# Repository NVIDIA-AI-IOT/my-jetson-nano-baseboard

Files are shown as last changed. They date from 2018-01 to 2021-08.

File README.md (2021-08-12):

# My Jetson Nano Baseboard

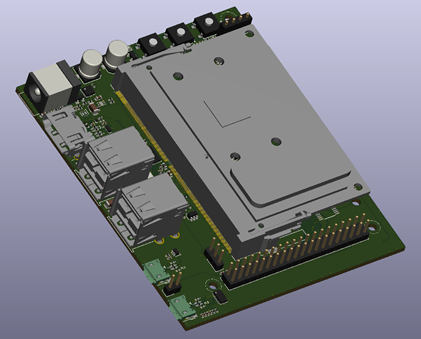
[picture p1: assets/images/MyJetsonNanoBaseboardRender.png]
Render of My Jetson Nano Baseboard

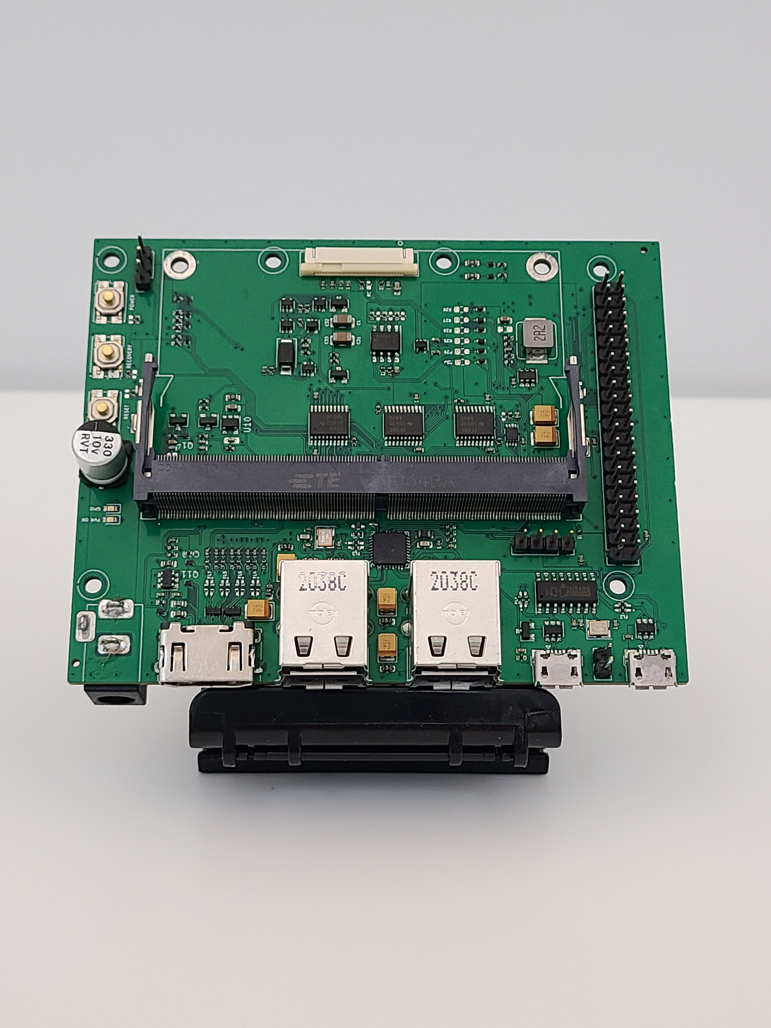
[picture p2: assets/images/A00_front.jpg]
Picture of My Jetson Nano Baseboard


This basic baseboard gives the user the foundation and the flexibility to design their own baseboard for the Jetson Nano. It also repurposes some of the Jetson Nano’s interface signals for simple beginner projects.

This baseboard, as designed, contains:
* A 5V, 4A DC barrel jack
* 4 USB 2.0 connectors
* An HDMI connector
* A UART-to-USB bridge
* A debug USB
* A 40-pin GPIO
* A servo header
* Three user-interactive buttons (power, reset, and force recovery)
* A flex connector for an OLED display

Use these files to kickstart your own application-specific baseboard or implement some quick and easy projects!

## Quick Start

You only need a computer to get started right now! For a more in-depth setup guide, check out `docs/setup.md`.
1.	Install the appropriate version of KiCAD, an open source schematic and layout design program, for your operating system [here](https://www.kicad.org/download/).
1.	Download this GitHub repository either as a ZIP or on the command line.
1.	Save the following symbol and footprint libraries to the “Design Files/Libraries” folder (you may have to make an account – alternatively, if you want the practice, you could try making them yourself):
	1.	[B3SL-1002P](https://octopart.com/b3sl-1002p-omron-9515385)
	1.	[TPD4E02B04DQAR](https://www.snapeda.com/parts/TPD4E02B04DQAR/Texas%20Instruments/view-part/)
	1.	[3-1734592-0](https://www.te.com/usa-en/product-3-1734592-0.html)
	1.	[DC-005-2.0A](https://www.snapeda.com/parts/DC-005/Best%20Inc./view-part/)
	1.	[ACM2012-201-2P-T001](https://www.snapeda.com/parts/ACM2012-201-2P-T001/TDK/view-part/1217094/)
	1.	[10029449-111RLF](https://octopart.com/10029449-111rlf-amphenol+icc+%2F+fci-90332945#CadModels)
	1.	[2309413-1](https://www.te.com/usa-en/product-2309413-1.html)

1.	Open the project (.pro) file in KiCAD.
1.	Add the symbol and footprint libraries as project-specific to your KiCAD program, following [this guide](https://support.snapeda.com/en/articles/2651507-how-to-import-into-kicad). You will know that the libraries are correctly loaded when there are no more boxes with question marks.
1.	You are now set up to tinker with the files and launch your own hardware designs!

Be sure to download the Jetson Nano Product Design Guide [here](https://developer.nvidia.com/embedded/downloads) (NVIDIA Developer account required) to help you with your design.

If you want to make your boards and test them, you’ll need the Jetson Nano module (not included, can be bought as part of the developer kit [here](https://developer.nvidia.com/embedded/jetson-nano-developer-kit)). It is also helpful to have electronics equipment like an oscilloscope, a multimeter, and a soldering iron.

## Questions and Improvements

If you have a suggestion, please open an [issue](https://github.com/NVIDIA-AI-IOT/my-jetson-nano-baseboard/issues/new) on GitHub.

Please share your projects with us on the [Jetson Developer Forums](https://forums.developer.nvidia.com/c/agx-autonomous-machines/jetson-embedded-systems/70).

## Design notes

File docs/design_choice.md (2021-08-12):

# Design Justifications

## Introduction

This document details choices made and tradeoffs considered in designing this board, with the aim of informing makers' design decisions and elucidating the design process.

To the extent possible, the board was designed for simplicity of manufacturing and affordability. Parts were selected from the manufacturer's (JLCPCB) parts library, and the number of resistors and capacitors was reduced by standardizing pullup and pulldown resistor (1k, 10k, or 100k) and decoupling capacitor (0.1uF) values. When a suggested layout was provided by a manufacturer on a datasheet, it was used. For ease of use, footprints of components that were not stuffed were indicated in silkscreen so they could be easily found, while stuffed components were not silkscreened to reduce clutter.

## Power

Power planes were used to improve power connections and raise current limits, and were placed on the exterior layers, which have thicker copper than the interior layers, to improve conductivity. Decoupling capacitors were added to power rails to filter out high-frequency noise.

No power protection is provided after the barrel jack, as it is assumed that the power supply is stable and at the correct voltage. Additional over/under current/voltage protection can be added by the user.

The topology of the Buck converter (U7) was determined using TI's WBENCH tool, and a 100 Ohm resistor was added in series with the resistor so that high-frequency noise could be injected during validation to measure stability.

## Signal Integrity

### Reducing Interference

Electrostatic discharge (ESD) and electromagnetic interference (EMI) can cause circuit malfunctions and damage on-board components. ESD diodes with at least 8kV protection were added to major interfaces, and were placed near the connectors to stop voltage spikes close to the source. Ground stitching vias were added in a uniform pattern around the board to prevent EMI. Each copper layer was filled with a GND plane where there were no other copper fills, which also helped balance the deposits on the board. For further EMI protection, optional common mode chokes footprints were also provided near connectors.

### Design for High Speed

High-speed interfaces were laid out first, and the design rules concerning inter-pair and intra-pair skew, via topology, and more in the Jetson Nano Product Design Guide were followed. Interface speeds are the following: 

| Interface/Signal | Speed | Type |
|---|---|---|
| HDMI | 5.94 Gbps | High-speed |
| UART | 5 Mbps max | Low-speed |
| I2C | 5 Mbps max | Low-speed |
| I2S | 3.125 Mbps max | Low-speed |
| SPI | 65 MHz max frequency | Medium-speed |
| USB2.0 | 480 Mbps | High-speed |
| GPIOs from module | ? | Low-speed |

HDMI was routed first, then USB2.0, then all else.

Differential pairs have strict spacing and trace width requirements, determined based on impedance requirements, that can be set in KiCAD using net classes. The length and skew of a differential pair can be adjusted using KiCAD's differential pair tools. Special care was taken for HDMI traces in particular since they are very high speed. The space under HDMI pads was voided to avoid introducing capacitive effects, and GND return vias were placed in the line of sight to any HDMI signal vias.

### Other considerations

A maximum of 45 degree angles were used during layout - anything sharper, and the signal may be damaged.

## Component Placement

The form factor was based on the Jetson Nano: a four-layer board was chosen, the same shape was used, connectors were placed in the same locations. This was helpful in avoiding potential interference between the sheaths of connectors plugged in at the same time. Interference of other connectors, including the fan header and GPIO header, was checked by drawing the outline of jumper wires. The form factor did create some challenges, notably with the OLED display - there wasn't enough space to support the display on the board, so the connector was placed to have the display cantilevered. To provide more support, two holes were drilled on either side of the connector, so that the user could design their own mounting scheme if they wanted to.

Components were placed together by functionality and by power requirements.

## Circuit Specifics

### Debug microUSB Connections

The transistor circuit detects whether the USB device is plugged in, which is necessary for interfacing with Tegra. Tegra's GPIO00 has a logic level of 1.8V, so the transistor circuit also acts as a level shifter to bring it to the USB level of 5V. This circuit is present on the existing Jetson Nano baseboard.

### EEPROM

The EEPROM is provided as an option for makers to write their own board firmware, which allows to differentiate between multiple versions of the same board. It is not required. The address of the EEPROM is 7'h57.

### UART to USB Bridge

CH340G was chosen due to its low cost, and the capacitor connections were determined based on the datasheet's application example. Because the module should be continually transmitting, CTS was grounded, RTS was left floating, and USB suspend/resume and remote wakeup were not used.

### Power ON/OFF Logic

Open-drain NAND gates are used due to timing requirements for power-on logic, as opposed to a D flipflop, and to reduce cost. Pullups R6 and R7 were added due to the gates being open-drain. The logic was simulated in LTSpice. 

The RC time constant of R2 and C32/C33 was chosen to be approximately 10s, even within resistor and capacitor tolerance, so that users can shut down the system within that time as expected. A large capacitance value was used since large resistors usually have undesirable parallel effects. 100 uF capacitors are large and expensive, so two 47uF capacitors were placed in parallel. Co-layout options (0805 and 1206) were provided so that the value of C32/C33 could be tuned during validation. R39 was added to limit current to the capacitors.

Finally, the buffers U1, U2, and U4 prevent loading effects from the S/R latch that might interfere with the logic.

### USB 2.0 Type A Hub

500 mA fuses and 100 uF capacitors were added to each connector, as per the USB specification. This prevents USB devices from drawing too much current and protects the module.

### Level Shifters

Level shifters are necessary because Tegra's GPIOs and UART signals have a 1.8V logic level, but 5V and 3.3V logic levels are expected, respectively. The GPIO header is compatible with PiHats and allows the user to power small devices from the header.

### OLED Display

All signals going to this display should be at 3.3V. The display was laid out using I2C, enabling users to practice using that protocol, although the display also supports 4-wire SPI as well as 8-bit 68XX and 80XX parallel microcontroller interfaces. The display's active-low reset is tied to the 3V3_PGOOD signal. The I2C address pin is pulled high, with the option of being pulled low.

Note that the connector's pin numbers are the opposite of the display's (i.e. pin 1 on the display is pin 24 on the board).

### HDMI Connections

A load switch was used with a current limit of 600 mA, the lowest possible for the load switch chip used. A load switch was used instead of a resettable fuse, which would be cheaper, because the HDMI specification requires the 5V power to be off when the module is in sleep mode.

## SODIMM Connector

Please do not force the module into the connector - doing so will irreparably damage it and cause signals to be misaligned.

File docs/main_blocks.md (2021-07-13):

# Functional Circuit Description

## Power

Power is provided via a barrel jack connector. The power supply should be 5V, 4A. 

> Please note that unlike the Jetson Nano, this baseboard's design does not allow for powering through the micro USB connector or the GPIO header.

A Buck converter is used to step down the voltage from 5V to 3.3V, and a low dropout regulator is used to translate the 3.3V rail to 1.8V.

| 5V | 3.3V | 1.8V |
|---|---|---|
| Jetson Nano Module | OLED Display  | Level Shifter |
| Debug microUSB | USB Hub Chip  | EEPROM |
| Servo Header | Level Shifter | |
| HDMI | HDMI | |
| GPIO Header | GPIO Header | |

Power required for each interface.

## Display

HDMI is provided as a display for the monitor. The HDMI lines use the DP1 class of signals on the module. The Jetson Nano module also supports DisplayPort signals, which can be added to the board.

## GPIO Header

This board replicates the Jetson Nano's 40-pin GPIO header. The pinout is compatible with the PiHat boards and is available on [pinout.xyz](https://pinout.xyz/). The GPIO header contains I2C, SPI, GPIOs, UART signals and 5V, 3.3V, and GND power rails.

## USB Connections

### Debug USB Header

The debug USB header is a microUSB type B connector. It enables the board to enter force recovery mode, in which the operating system is not loaded and the board becomes a USB device that can be written to from a host computer. It corresponds to USB0 on the module.

### UART to USB Bridge

The UART to USB Bridge is a microUSB type B connector that allows the user to connect a device to the Jetson Nano via UART. It corresponds to the UART2 lines on the module.

### USB 2.0 Type A

There are four USB 2.0 Type A connections. These can be used for keyboards, mouses, cameras, and more. These are managed through a USB hub chip and correspond to the USB1 lines on the module.

## EEPROM

The EEPROM is used interally to identify the board and is provided as an option for developers who wish use it in writing their own firmware. It can be written to on the I2C2 lines, and its address is 7'h57.

## OLED Display

A flex connector for an OLED display is provided using the I2C0 lanes. The schematic can be edited to use three or four wire SPI or 8-bit 68XX or 80XX parallel to interface with the OLED Display.

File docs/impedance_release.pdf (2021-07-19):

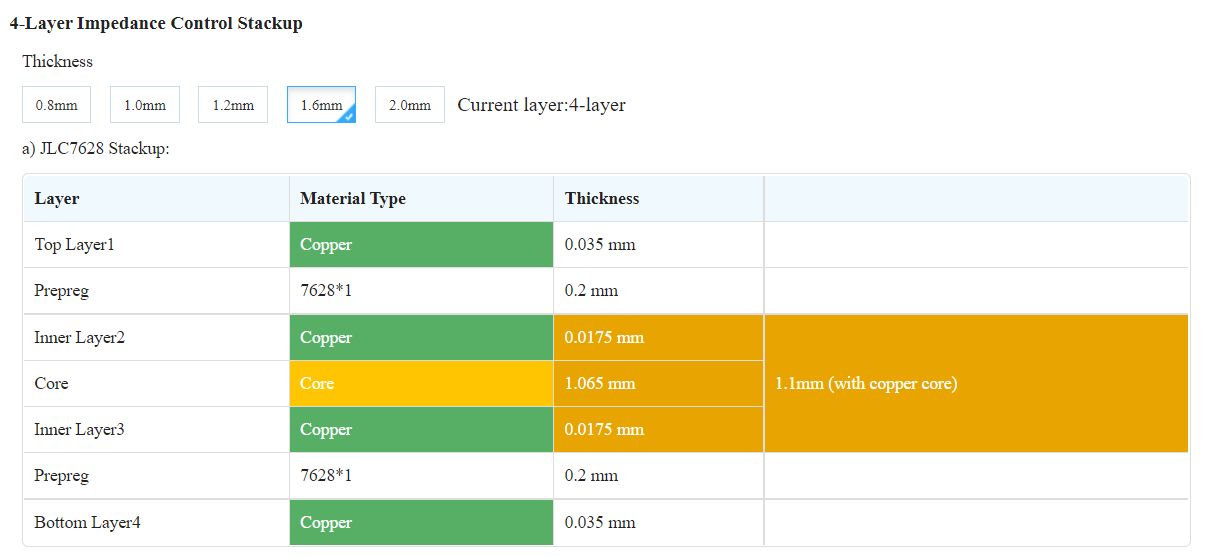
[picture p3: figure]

Using standard JLCPCB 1.6mm stackup, https://cart.jlcpcb.com/impedance

All tolerances +/- 10%

Single Ended | DEZ | SEZ | LW | LineGap | Ref (above) | Ref (below)
TOP | | 50 | 0.1016 | | | L2
BOTTOM | | 50 | 0.1016 | | L3

Target impedance for USB pairs is 90 Ohm. Target impedance for HDMI pairs is 100 Ohm.

Differential (edge) | DEZ | SEZ | LW | LineGap | Ref (above) | Ref (below)
TOP | 85 | | 0.2 | 0.102 | | L2
TOP | 90 | | 0.18 | 0.102 | | L2
TOP | 95 | | 0.1524 | 0.102 | | L2
TOP | 100 | | 0.1524 | 0.1524 | | L2
TOP | 105 | | 0.1524 | 0.179 | | L2
BOTTOM | 85 | | 0.2 | 0.102 | L3
BOTTOM | 90 | | 0.18 | 0.102 | L3
BOTTOM | 95 | | 0.1524 | 0.102 | L3
BOTTOM | 100 | | 0.1524 | 0.1524 | L3
BOTTOM | 105 | | 0.1524 | 0.179 | L3

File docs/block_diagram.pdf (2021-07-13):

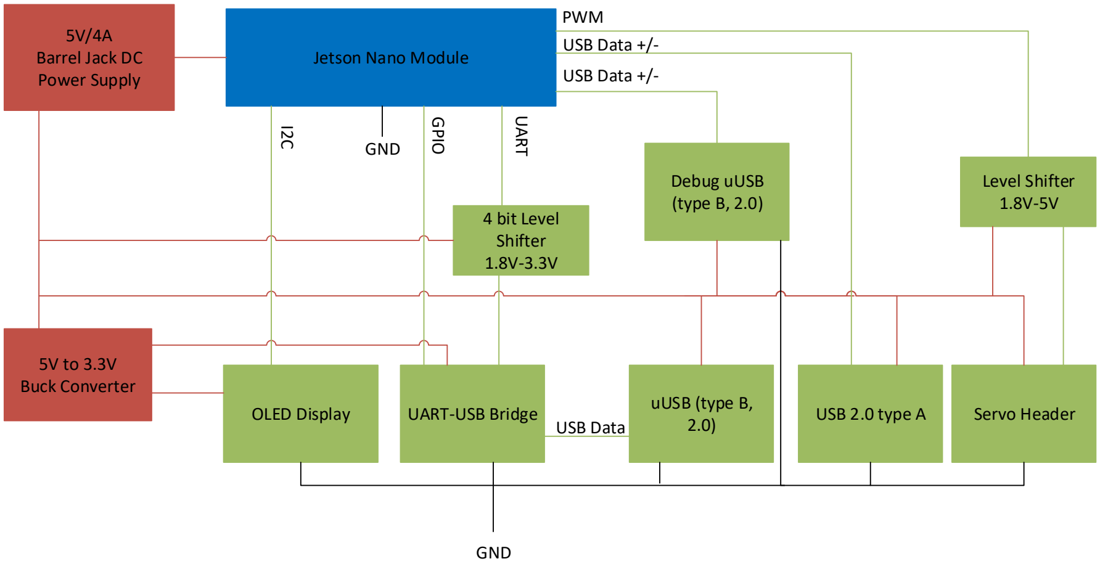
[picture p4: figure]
OLED Display; 5V/4A Barrel Jack DC Power Supply; 5V to 3.3V Buck Converter; Jetson Nano Module; UART-USB Bridge; Servo Header uUSB (type B,; 2.0) USB 2.0 type A; PWM; GND; 4 bit Level Shifter 1.8V-3.3V; GPIO; USB Data +/-; USB Data; Debug uUSB (type B, 2.0); UART; Level Shifter 1.8V-5V

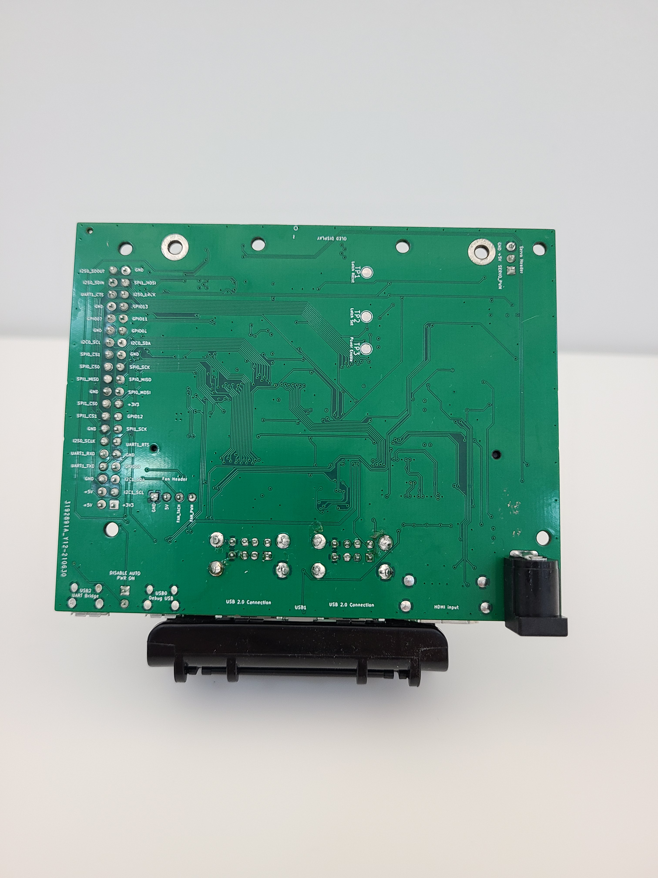
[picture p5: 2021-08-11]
assets/images/A00_back.jpg

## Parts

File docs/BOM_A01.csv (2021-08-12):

Datasheet | Part Number | Designator | Footprint | LCSC Part
https://datasheet.lcsc.com/lcsc/1810191219_Samsung-Electro-Mechanics-CL05B104KO5NNNC_C1525.pdf | CL05B104KO5NNNC | C10, C11, C12, C13, C14, C15, C16, C28, C29, C30, C36, C37, C38, C39, C40, C44, C47, C48, C49, C50, C51, C52, C53, C54, C55, C56, C59, C60, C62, C63, C70, C71 | 0402 | C1525
https://datasheet.lcsc.com/szlcsc/Samsung-Electro-Mechanics-CL05A475MP5NRNC_C23733.pdf | CL05A475MP5NRNC | C2, C8, C17 | 0402 | C23733
https://datasheet.lcsc.com/lcsc/1810191219_Samsung-Electro-Mechanics-CL10A106KP8NNNC_C19702.pdf | CL10A106KP8NNNC | C20, C72 | 0603 | C19702
https://datasheet.lcsc.com/szlcsc/AVX-TAJB107K006RNJ_C16133.pdf | TAJB107K006RNJ | C22, C23, C66, C67, C68, C69 | CASE-B_3528 | C16133
https://datasheet.lcsc.com/lcsc/2105211807_Honor-Elec-RVT1A331M0810_C113284.pdf | RVT1A331M0810 | C24 | CAP-SMD | C113284
https://datasheet.lcsc.com/lcsc/1811141710_FH-Guangdong-Fenghua-Advanced-Tech-0402CG6R8C500NT_C1576.pdf | 0402CG6R8C500NT | C25 | 0402 | C1576
https://datasheet.lcsc.com/szlcsc/Samsung-Electro-Mechanics-CL05A105KA5NQNC_C52923.pdf | CL05A105KA5NQNC | C3, C4, C18, C19 | 0402 | C52923
https://datasheet.lcsc.com/lcsc/1810221121_Samsung-Electro-Mechanics-CL31A476MPHNNNE_C96123.pdf | CL31A476MPHNNNE | C32, C33 | 1206 | C96123
https://datasheet.lcsc.com/lcsc/1809291524_FH-Guangdong-Fenghua-Advanced-Tech-0402B102K500NT_C1523.pdf | 0402B102K500NT | C41 | 0402 | C1523
https://datasheet.lcsc.com/szlcsc/Guangdong-Fenghua-Advanced-Tech-0603B103K500NT_C57112.pdf | 0603B103K500NT | C45, C61 | 0603 | C57112
https://datasheet.lcsc.com/szlcsc/Guangdong-Fenghua-Advanced-Tech-0402CG150J500NT_C1548.pdf | 0402CG150J500NT | C57, C58, C64, C65 | 0402 | C1548
https://datasheet.lcsc.com/lcsc/1811141731_FH-Guangdong-Fenghua-Advanced-Tech-0402CG330J500NT_C1562.pdf | 0402CG330J500NT | C73, C74 | 0402 | C1562
https://datasheet.lcsc.com/lcsc/2007141104_MDD-Microdiode-Electronics-SS14_C2480.pdf | SS14 | D1 | SMA,DO-214AC | C2480
https://datasheet.lcsc.com/lcsc/2005212035_TECH-PUBLIC-TPD1E10B06DPYR-TP_C558445.pdf | TPD1E10B06DPYR-TP | D12, D13, D14, D15, D16, D17 | DFN1006-2 | C558445
https://datasheet.lcsc.com/lcsc/1809131529_Texas-Instruments-TPD4E02B04DQAR_C106794.pdf | TPD4E02B04DQAR | D18, D19 | uSON-10 | C106794
https://datasheet.lcsc.com/szlcsc/2005211235_TECH-PUBLIC-TPUSBLC6-2SC6_C558442.pdf | USBLC6-2SC6 | D2, D5, D9, D10, D11, D20 | SOT-23-6 | C558442
https://datasheet.lcsc.com/lcsc/1809051321_LRC-LBAS70-05LT1G_C131857.pdf | LBAS70-05LT1G | D4 | SOT-23-3 | C131857
https://datasheet.lcsc.com/szlcsc/Everlight-Elec-19-217-GHC-YR1S2-3T_C72043.pdf | 19-217/GHC-YR1S2/3T | D6 | LED_0603 | C72043
https://datasheet.lcsc.com/lcsc/1811101510_Everlight-Elec-19-217-BHC-ZL1M2RY-3T_C72041.pdf | 19-217/BHC-ZL1M2RY/3T | D7 | LED_0603 | C72041
https://datasheet.lcsc.com/lcsc/1811141711_Sunlord-GZ2012D601TF_C1017.pdf | GZ2012D601TF | FB1 | 0805 | C1017
https://datasheet.lcsc.com/lcsc/1811151421_Ckmtw-Shenzhen-Cankemeng-B-2100S02P-A110_C124375.pdf | B-2100S02P-A110 | J1 | HDR-TH_2P-P2.54-V | C124375
https://file.elecfans.com/web1/M00/BA/94/o4YBAF6eu2GABUqoAAdPfgsQimA612.pdf?filename=210S-1_2P.pdf | C124376 | J10 | HDR-TH_3P-P2.54-V | C124376
http://portal.fciconnect.com/Comergent//fci/drawing/10029449.pdf | 10029449-111RLF | J11 | HDMI SMT | C427307
https://www.te.com/usa-en/product-2-1734839-4.html | 2-1734839-4 | J2 | 24 pin SMT | -
https://file.elecfans.com/web1/M00/A7/25/pIYBAF2B1q6AKkTfABbJAnUjDHU127.pdf?filename=DC-005-5A-2.0.pdf | DC-005-5A-2.0 | J3 | THT | C381116
https://file.elecfans.com/web1/M00/BA/94/o4YBAF6eu2GABUqoAAdPfgsQimA612.pdf?filename=210S-1_2P.pdf | 210-91-04GB01 | J4 | THT | C390680
https://www.te.com/usa-en/product-2309413-1.html | 2309413-1 | J5 | SMT | -
https://file.elecfans.com/web1/M00/BA/94/o4YBAF6eu2GABUqoAAdPfgsQimA612.pdf?filename=210S-1_2P.pdf | 12251220ANG0S115001 | J6 | HDR-TH_40P-P2.54-V-M-R2-C20-S2.54 | C429965
https://datasheet.lcsc.com/lcsc/1912111437_Amphenol-ICC-10103594-0001LF_C428495.pdf | 10103594-0001LF | J7 | MICRO-USB-SMD | C428495
https://datasheet.lcsc.com/lcsc/1912111437_Amphenol-ICC-10103594-0001LF_C428495.pdf | 10103594-0001LF | J8 | MICRO-USB-SMD | C428495
https://www.molex.com/webdocs/datasheets/pdf/en-us/0672983090_IO_CONNECTORS.pdf | 672983090 | J9, J12 | USB-THT | C588408
https://datasheet.lcsc.com/lcsc/1912111437_Sunlord-MWSA0503S-2R2MT_C408408.pdf | MWSA0503S-2R2MT | L1 | SMD-5.2x5.4x2.8 | C408408
https://datasheet.lcsc.com/lcsc/1811081616_Murata-Electronics-LQP15MN1N2B02D_C77117.pdf | LQP15MN1N2B02D | L2 | 0402 | C77117
https://datasheet.lcsc.com/lcsc/1810262112_UG-Univision-Semicon-UG-2864KSWMG01_C88331.pdf | UG-2864KLBMG01 | OLED Display | - | C88331
https://www.fairchildsemi.com/datasheets/2N/2N7002.pdf | 2N7002 | Q1, Q2, Q5 | SOT-23 | C8545
https://www.diodes.com/assets/Datasheets/ds31854.pdf | DMN26D0UT-7 | Q3, Q4, Q6, Q7, Q9, Q10, Q11, Q12, Q13, Q14 | SOT-523 | C211407
https://www.diodes.com/assets/Datasheets/ds31835.pdf | MMBT3904 | Q8 | SOT-23 | C20526
https://datasheet.lcsc.com/szlcsc/Uniroyal-Elec-0402WGF1002TCE_C25744.pdf | 0402WGF1002TCE | R1, R5, R6, R7, R13, R14, R15, R17, R20, R24, R33, R34, R35, R40, R50, R52, R54, R56, R58, R71, R72, R79, R89, R90 | 0402 | C25744
https://datasheet.lcsc.com/lcsc/1811022110_UNI-ROYAL-Uniroyal-Elec-0402WGF2201TCE_C25879.pdf | 0402WGF2201TCE | R10 | 0402 | C25879
https://datasheet.lcsc.com/lcsc/1811011222_UNI-ROYAL-Uniroyal-Elec-0402WGF3901TCE_C51721.pdf | 0402WGF3901TCE | R11 | 0402 | C51721
https://datasheet.lcsc.com/lcsc/1810111814_UNI-ROYAL-Uniroyal-Elec-0402WGF1003TCE_C25741.pdf | 0402WGF1003TCE | R12, R18, R19, R38, R82, R83, R84, R85, R86, R87, R88 | 0402 | C25741
https://datasheet.lcsc.com/lcsc/1810301112_UNI-ROYAL-Uniroyal-Elec-0402WGF5101TCE_C25905.pdf | 0402WGF5101TCE | R16 | 0402 | C25905
https://datasheet.lcsc.com/lcsc/1810301322_UNI-ROYAL-Uniroyal-Elec-0402WGF3003TCE_C25774.pdf | 0402WGF3003TCE | R2 | 0402 | C25774
https://datasheet.lcsc.com/lcsc/1809140113_UNI-ROYAL-Uniroyal-Elec-0402WGF1000TCE_C25076.pdf | 0402WGF1000TCE | R21, R39 | 0402 | C25076
https://datasheet.lcsc.com/szlcsc/Uniroyal-Elec-0402WGF1001TCE_C11702.pdf | 0402WGF1001TCE | R23 | 0402 | C11702
https://datasheet.lcsc.com/szlcsc/Uniroyal-Elec-0402WGF1202TCE_C25752.pdf | 0603WAF1202T5E | R3 | 603 | C22790
https://datasheet.lcsc.com/lcsc/1811081724_UNI-ROYAL-Uniroyal-Elec-0603WAF1500T5E_C22808.pdf | 0603WAF1500T5E | R32, R37 | 0603 | C22808
https://datasheet.lcsc.com/szlcsc/Uniroyal-Elec-0402WGF4701TCE_C25900.pdf | 0402WGF4701TCE | R4, R22 | 0402 | C25900
https://datasheet.lcsc.com/lcsc/1809301716_UNI-ROYAL-Uniroyal-Elec-0402WGF1004TCE_C26083.pdf | 0402WGF1004TCE | R43 | 0402 | C26083
https://datasheet.lcsc.com/lcsc/1811151223_UNI-ROYAL-Uniroyal-Elec-0402WGF5100TCE_C25123.pdf | 0402WGF5100TCE | R59, R60, R61, R62, R63, R64, R65, R66 | 0402 | C25123
https://datasheet.lcsc.com/lcsc/1811081714_UNI-ROYAL-Uniroyal-Elec-0603WAF1801T5E_C4177.pdf | 0603WAF1801T5E | R77, R78 | 603 | C4177
https://datasheet.lcsc.com/szlcsc/Uniroyal-Elec-0402WGF0000TCE_C17168.pdf | 0402WGF0000TCE | R8, R31, R36, R41, R42, R44, R46, R47, R48, R49, R57, R67, R68, R69, R70, R73, R74, R75, R76 | 0402 | C17168
https://datasheet.lcsc.com/lcsc/1811081724_UNI-ROYAL-Uniroyal-Elec-0603WAF3602T5E_C23147.pdf | 0603WAF3602T5E | R80 | 0603 | C23147
https://datasheet.lcsc.com/szlcsc/Uniroyal-Elec-0402WGF1203TCE_C25750.pdf | 0402WGF1203TCE | R81 | 0402 | C25750
https://datasheet.lcsc.com/lcsc/1811081713_UNI-ROYAL-Uniroyal-Elec-0603WAF1102T5E_C25950.pdf | 0603WAF1102T5E | R91 | 0603 | C25950
https://datasheet.lcsc.com/lcsc/2002271432_XKB-Connectivity-TS-1187A-C-E-B_C318887.pdf | TS-1187A-C-E-B | S1, S2, S3 | SMD-SW-4_5.1x5.1x2.5 | C318887
https://datasheet.lcsc.com/lcsc/1810051613_TECHFUSE-SMD0603-050_C69679.pdf | SMD0603-050 | TH1, TH2, TH3, TH4 | 0603 | C69679
https://datasheet.lcsc.com/lcsc/1804240020_Nexperia-74LVC1G126GV-125_C12520.pdf | 74LVC1G126GW,125 | U1, U4 | SOT-353 | C55052
https://datasheet.lcsc.com/lcsc/1809291208_XI-AN-Aerosemi-Tech-MT9700_C89855.pdf | MT9700 | U10 | SOT-23-5 | C89855
https://datasheet.lcsc.com/lcsc/1809291612_Texas-Instruments-TXB0102DCUR_C60709.pdf | TXB0102DCUR | U15 | VSSOP-8_2.0x2.3x0.5P | C60709
https://datasheet.lcsc.com/lcsc/2008191806_WCH-Jiangsu-Qin-Heng-CH340G_C14267.pdf | CH340G | U16 | SOIC-16_3.9x9.9x1.27P | C14267
https://datasheet.lcsc.com/lcsc/1912112237_Microchip-Tech-AT24CS01-SSHM-T_C461563.pdf | AT24CS01-SSHM | U18 | SOIC-8 | C461563
https://datasheet.lcsc.com/lcsc/2008250208_ON-Semiconductor-MC74VHC1G07DFT2G_C603274.pdf | MC74VHC1G07DFT2G | U2 | TSSOP-5 | C603274
https://datasheet.lcsc.com/szlcsc/1810010411_Diodes-Incorporated-AP2281-3WG-7_C128634.pdf | AP2281-3WG-7 | U22 | SOT-26-6 | C128634
https://datasheet.lcsc.com/lcsc/1809200830_Microchip-Tech-USB2514B-AEZC-TR_C16251.pdf | USB2514B-AEZC-TR | U23 | QFN-36_6x6x05P | C16251
https://datasheet.lcsc.com/lcsc/1809111614_ON-Semiconductor-MC74VHC1G01DFT1G_C150244.pdf | MC74VHC1G01DFT1G | U3, U24 | SOT-353 | C150244
https://datasheet.lcsc.com/lcsc/1809192314_Texas-Instruments-TXS0108EPWR_C17206.pdf | TXS0108EPWR | U5, U6, U9 | TSSOP-20_4.4x6.5x0.65P | C17206
https://datasheet.lcsc.com/lcsc/2010150204_Texas-Instruments-TLV62569PDDCR_C398365.pdf | TLV62569PDDC | U7 | SOT-23-Thin-6 | C398365
https://datasheet.lcsc.com/lcsc/1912112237_Richtek-Tech-RT9193-18GU5_C425792.pdf | RT9193-18GU5 | U8 | SC70-5 | C425792
https://datasheet.lcsc.com/lcsc/2103291204_Yangxing-Tech-X322524MMB4SI_C70583.pdf | X322524MMB4SI | Y1 | SMD-3225_4P | C70583
https://datasheet.lcsc.com/szlcsc/Yangxing-Tech-X322512MSB4SI_C9002.pdf | X322512MSB4SI | Y2 | SMD-3225_4P | C9002

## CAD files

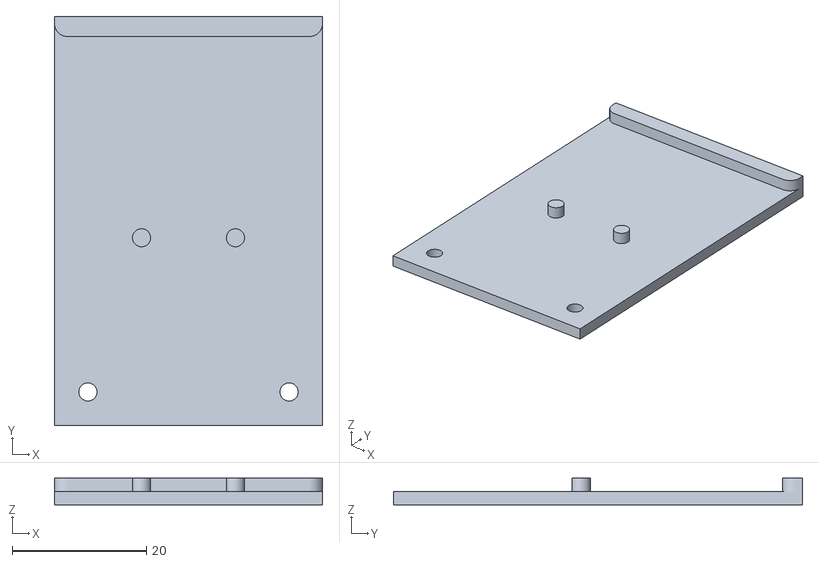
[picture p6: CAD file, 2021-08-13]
sampleproj/OLED Display Support.stl
40.0 x 61.0 x 4.00

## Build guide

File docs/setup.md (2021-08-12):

# Getting Started with My Jetson Nano Baseboard

## 0. Introduction

My Jetson Nano Baseboard enables makers to design their own baseboards for the Jetson Nano module. The provided design differs from the Jetson Nano's baseboard in that it contains fewer high-speed interfaces, although these can be added by the maker. The My Jetson Nano Baseboard also includes sample projects that allow the user to experiment with I2C and GPIOs.

This baseboard, as designed, contains:

- A 5V, 4A DC barrel jack
- 4 USB 2.0 connectors
- An HDMI connector
- A UART-to-USB bridge
- A debug USB
- A 40-pin GPIO
- A servo header
- Three user-interactive buttons (power, reset, and force recovery)
- A flex connector for an OLED display

These interfaces can be customized according to the maker's needs. The files are provided as-is and may contain errors (if you find one, open an issue).

Use these files to kickstart your own application-specific baseboard or implement some quick and easy projects! It is our hope that this project will contribute to the Open Hardware movement.

## 1. Setting Up Software

These files were created with KiCAD, a free and open-source electronics design suite including schematic capture and PCB layout. Although there are other FOSS electronics programs, KiCAD is widespread and has the most extensive professional features.

You can download KiCAD from their official website [here](https://www.kicad.org/download/).

KiCAD itself needs very little setup, but these files require you to set up some libraries. First, download the files in this repository as a ZIP or on the command line. 

> If you download my-jetson-nano-baseboard as a ZIP, be sure to unzip the folder. If you do not do this, KiCAD will not be able to access sub-pages in the repository and your schematic will be empty.

Some symbol and footprint libraries are included with the download of the files in this repository, located in the design/libraries folder. Others will need to be downloaded:

1.	[B3SL-1002P](https://octopart.com/b3sl-1002p-omron-9515385)
1.	[TPD4E02B04DQAR](https://www.snapeda.com/parts/TPD4E02B04DQAR/Texas%20Instruments/view-part/)
1.	[DC-005-2.0A](https://www.snapeda.com/parts/DC-005/Best%20Inc./view-part/)
1.	[ACM2012-201-2P-T001](https://www.snapeda.com/parts/ACM2012-201-2P-T001/TDK/view-part/1217094/)
1.	[10029449-111RLF](https://octopart.com/10029449-111rlf-amphenol+icc+%2F+fci-90332945#CadModels)
1.	[67298-3090-0](https://octopart.com/67298-3090-molex-7124952#Specs)
1.	[2309413-1](https://www.te.com/usa-en/product-2309413-1.html)

To set these up, open the project (.pro) file and navigate to Preferences > Manage Symbol Libraries > Project Specific Libraries, and add the relevant library with the plus sign. Repeat for footprint libraries. 

Upon reopening the schematic file, boxes with question marks should be replaced by symbols. If the boxes with question marks remain, you may have to re-select the proper symbol for the pat from the library.

To run the sample projects, you will need several Python libraries. They can be installed using pip with the following command:

> pip3 install Jetson.GPIO smbus2 machine

Because this operation requires internet, I recommend switching the module to the official baseboard and connecting it to the internet via Ethernet.

## 2. Editing & Designing

Printed Circuit Boards can be manufactured directly from the provided Gerber files, though you may wish to edit the files to better suit your use. If you are unfamiliar with KiCAD, SparkFun has a [nice beginner's guide](https://learn.sparkfun.com/tutorials/beginners-guide-to-kicad) that covers the workflow and basic actions.

Here are some changes you may want to make:

1.	Adding or removing an interface
	- The Jetson Nano Product Design Guide, available on NVIDIA's [Jetson Downloads Center](https://developer.nvidia.com/embedded/downloads), details the signals on the Jetson Nano module and the interfaces it supports.
1.	Changing the form factor of the board
	- This can be done easily in KiCAD by changing the "Edge Cuts" layer to reflect your preferred shape, moving the components outside of that zone, and re-routing.
1.	Replacing parts of the design
	- If the parts specified are no longer available, too expensive, or you want to change them for another reason, replace them on the schematic. Be sure to pick a new footprint for your chosen part.

If you choose to change the files, be sure to run a Design Rules Check (in KiCAD, represented by a ladybug) and review your design yourself in order to limit mistakes.

### Example: Removing the HDMI Connector

When removing the HDMI connector, you'll have to remove the connector itself and the peripherals that are required for the proper operation of HDMI. These will be on the "HDMI Connections" pages. Remove every part on those pages, then look at the rest of the document to identify any HDMI connections you've broken. In this case, there are a number of HDMI signals going to the module - you will want to mark those as "not connected".

Having removed the HDMI connections on the schematic, you then need to remove them on the layout. Generate a new netlist from the schematic, then load that into the PCB editor. You'll see far fewer components than before - you can use the extra space to make the board smaller, if you wish.

## 3. Making your boards

PCBs can be manufactured pretty inexpensively nowadays, so it's possible to make your boards. When choosing a manufacturer, consider the lead time, cost, and functionality. Many will give you a price estimate directly on their websites when uploading your files. Note that some parts, like the 260-pin SODIMM connector will be difficult to solder by hand, so it's helpful to have the manufacturer do that for you (not all support assembly). If you do have to solder complicated components by hand, it's helpful to order stencils, which will allow you to deposit solder paste very precisely. Some places will add them in for free or cheaply when you place your order.

Manufacturers will ask for Gerber files (provided as `manufacturing/gerbers_release.zip`), which contain instructions on where to lay copper on each layer. Drill files, also in that .zip, are also necessary to drill vias. If you are asking for assembly, the `manufacturing/assemble-top-pos.csv` is required.

## 4. Verifying the boards

There are four main stages to validation:
* Bringup
	* Before powering on the board, check for shorts between power rails, and ensure the characteristics of diodes and transistors are accurate to the datasheet. This is the most important part of validation, and for the most part can be done with just a multimeter.
* Functionality
	* Powering on the board and testing all interfaces to make sure they work. This can be done with scripts in some cases - those are in `../validation`.
* Power
	* Testing the efficiency, noise, and other characteristics of power sources, as well as ensuring power sequence signals are correct. Needs an oscilloscope.
* IO Electrical
	* Ensuring that interfaces meet electrical specifications, where appropriate. This must be done with an oscilloscope.

Enjoy your new baseboard!

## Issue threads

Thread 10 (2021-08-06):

Make silkscreen more readable

wolframalexa, 2021-08-06:
* Increase silkscreen size from 0.5x0.5mm to 0.438x0.7mm to make the text more readable.
* Add polarity for all ICs and polarized components to aid in soldering
* Add silkscreen on front for 40-pin header

Closed 2021-08-13.

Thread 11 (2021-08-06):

Incorrect footprints

wolframalexa, 2021-08-06:
* Flip DC Jack (J1) footprint to solder it on top
* GPIO header flipped - pin 1 should be towards outside edge of board

Closed 2021-08-13.

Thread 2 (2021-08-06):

Power LED does not light up on some boards

wolframalexa, 2021-08-06:
**Problem**
On some boards, the power LED D6 does not light, even though the board completes its power-on sequence and has booted normally.

**Release**
A00, no modifications

**Observed Behavior**
* The LED is the correct direction
* The board completes its power on sequence and the software functions as expected
* GPIO04 remains LOW at 0.6V, even though it should be driven HIGH upon power-up
* There is no measured voltage drop across R32
* There is an insufficient voltage drop across D6

**Root Cause Theory**
The gate threshold voltage varies depending on the individual transistor. It could be that this transistor has a higher V_GS and does not turn on when GPIO04 is at 0.6V. Additionally, the transistor Q7 could be misaligned.

**Suggested Next Steps**
* Investigate behavior of GPIO04, which should be HIGH upon power-on. Remove R31 to ensure no loading effects from transistor.
* Change all transistors DMN26D0UFB4-7 to the DMN26D0UT-7, which is in a larger SOT-523 package, to avoid misalignments.

wolframalexa, 2021-08-09:
Added 10k pullup R89 to 1v8 between R31 and gate of Q7.

Closed 2021-08-13.

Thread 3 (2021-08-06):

Low-resolution HDMI (1280x720)

wolframalexa, 2021-08-06:
**Problem**
The maximum HDMI resolution seems to be 1280x720, whereas the Jetson Nano achieves a resolution of 2560x1440. As a result, the display appears zoomed in.

**Release**
A00, no modifications

**Observed Behavior**
* This is present on all boards, with the same module as on the official baseboard - probably a hardware design issue, and not a software issue
* The resolution on the official Jetson Nano is twice that of "My Jetson Nano Baseboard"

**Root Cause Theory**
Resistor values may need to be tuned for better resolutions. Additionally, an EEPROM may be read to confirm HDMI resolution.

**Suggested Next Steps**
Investigate L4T behavior with regard to HDMI and resistor tuning on CEC line.

Closed 2021-08-13.

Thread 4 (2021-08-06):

Some USB 2.0 type A ports are not functional

wolframalexa, 2021-08-06:
**Problem**
Some USB ports on some boards do not respond when a USB mouse or keyboard is plugged into them.

**Observed Behavior**
When a USB mouse or keyboard is plugged into one of the four type A ports, it occasionally does not work (the pointer does not move, no text appears on screen). This hinders the ability for the user to interact with the display, and to use the USB devices they need.

**Root Cause Theory**
This is only present on some ports on some boards; it could be a manufacturing or hub chip error.

**Suggested Next Steps**
* Visually check all USB components to ensure there is no damage
* Ensure hub chip is strapped correctly
* Ensure USB layout guidelines are followed for signal integrity

wolframalexa, 2021-08-09:
Soldermask clearance around the USB pads is not sufficient; as a result, during rework, technicians had to scrape the mask off. This could cause poor electrical connections. I added additional soldermask clearance around the USB pads in A01.

Closed 2021-08-13.

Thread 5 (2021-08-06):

Fan PWM signal not in compliance

wolframalexa, 2021-08-06:
**Problem**
Users cannot use a fan, because the fan PWM signal is not in electrical compliance.

**Observed Behavior**
GPIO14 provides a nice PWM signal, but the signal becomes less crisp as it goes through the level shifter. In both images below,   the blue line is the FAN_PWM_LS node. Yellow: left = GPIO14, right = FAN_PWM_INV.

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

The transistor Q3 should invert the PWM signal, but does not appear to do so.

**Root Cause Theory**
At 20kHz, it is unlikely the fan signal is switching too fast for the transistor. It may be due to a transistor misalignment; switch from the DMN26D0UFB4-7 to the DMN26D0UT-7, which is in a larger SOT-523 package, to avoid misalignments.

**Suggested Next Steps**
Ask a more experienced engineer. May need a larger pullup, or more power control.

wolframalexa, 2021-08-09:
Removed Q3 and measured the fan PWM remaining high - showing that this is likely due to a transistor misalignment. Will switch to larger package for A01.

Closed 2021-08-13.

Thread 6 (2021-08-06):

OLED display does not fit in specified connector

wolframalexa, 2021-08-06:
**Problem**
The specified OLED display does not fit in the specified connector. Users cannot use the display.

**Release**
A00, no modifications

**Observed Behavior**
The connector is too small for the display.

**Root Cause Theory**
Mistakes were made.

**Suggested Next Steps**
Choose new connector for display.

wolframalexa, 2021-08-11:
0.7mm pitch FFC/FPC connectors are rare, so I'm changing both the display and the connector for greater accessibility. This will be fixed in A01.

Closed 2021-08-13.

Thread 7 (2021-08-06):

Fails sleep/wake software cycle

wolframalexa, 2021-08-06:
**Problem**
Board cannot be wake from software; the physical button must be pushed.

**Release**
A00, no modifications

**Observed Behavior**
When running the `validation/sleep_func.sh` script, the device does not wake until the power button is pushed.

**Root Cause Theory**
An issue with how L4T interacts with the baseboard.

**Suggested Next Steps**
* Probe power logic signals to ensure sequencing is correct
* Read L4T documentation for power design

wolframalexa, 2021-08-09:
Edited validation script with new sleep/wake command - hardware is validated. Worth noting that rtc0 is the default clock to wake with - not rtc1. Further information can be found on NVIDIA's forums here: https://forums.developer.nvidia.com/t/rtc-wakeup-not-happening-in-jetson-tx2-4gb/173047

Closed 2021-08-09.

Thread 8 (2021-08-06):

Servo PWM signal does not switch logic levels, remains high

wolframalexa, 2021-08-06:
**Problem**
When running the `sampleproj/servo_pwm.py` script, SERVO_PWM remains high, even as the GPIO07 pin outputs a PWM signal.

**Release**
A00, no modifications

**Observed Behavior**
Servo PWM remains high even when PWM script is run.

GPIO07 at 40-pin header:
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

SERVO_PWM at servo header:
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

**Root Cause Theory**
The pullup could be too strong; the transistor connection may not be consistent across boards. This is another issue that switching to a larger package transistor should fix.

**Suggested Next Steps**
* Switch to larger package transistor (as in issue #5 & 2)
* Test additional boards to ensure transistor connection remains consistent

wolframalexa, 2021-08-09:
Additional boards also have this issue. Likely due to transistor misalignment - will change for A01.

Closed 2021-08-13.

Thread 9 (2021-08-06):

Incorrect SODIMM connector

wolframalexa, 2021-08-06:
Use TE's 2309413-1 instead of ADDR0111-P005A for J5. The key is the opposite and the 2309413-1's key placement is correct.

Closed 2021-08-13.

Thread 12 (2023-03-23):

Internet Component

jccatilo, 2023-03-23:
Hi!! Thank you very much for this, I've got the imports working and now designing my own pcb. I'm working on a custom basedboard for jetson nano. I didn't see any component for internet connectivity like ethernet ports or wifi cards. or is there and I've just overlooked them? thanks!

CharlesMod, 2023-07-28:
WiFi is accomplished over the PCIe bus, See chapter 8 of the product design guide for jetson nano to get details on the ethernet implementation

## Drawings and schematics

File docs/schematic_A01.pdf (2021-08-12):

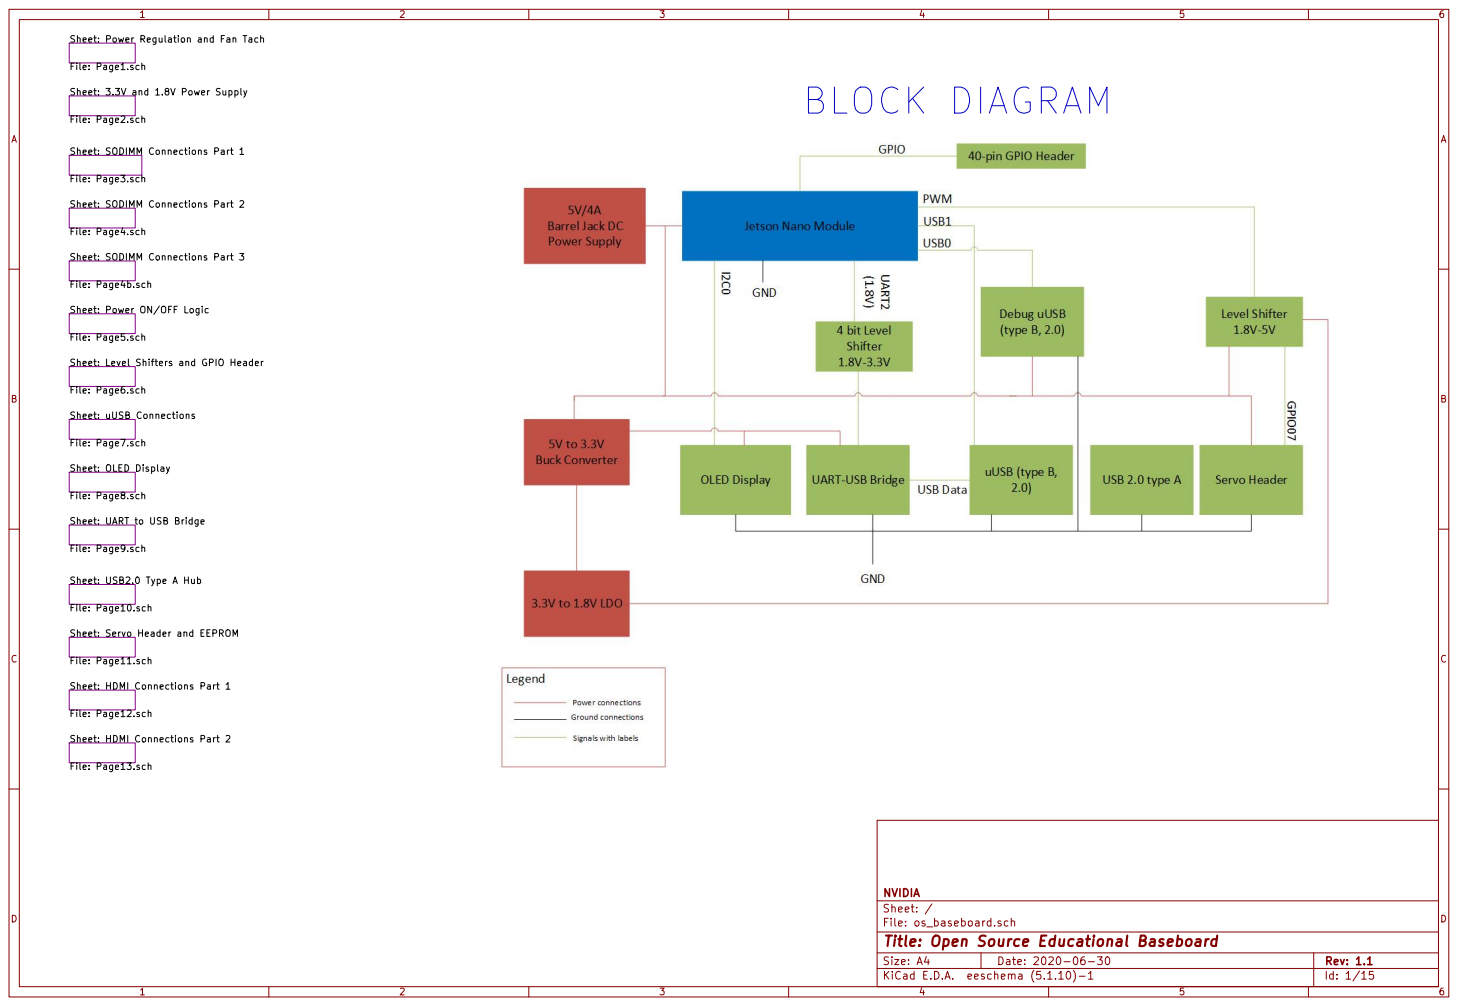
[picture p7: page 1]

File: Page2.sch Sheet: SODIMM Connections Part 1 File: Page3.sch Sheet: SODIMM Connections Part 2 File: Page4.sch Sheet: Level Shifters and GPIO Header File: Page6.sch Sheet: uUSB Connections File: Page7.sch
File: Page11.sch Sheet: SODIMM Connections Part 3 File: Page4b.sch Sheet: HDMI Connections Part 1 File: Page12.sch Sheet: HDMI Connections Part 2 File: Page13.sch

Sheet: Power Regulation and Fan Tach

Sheet: 3.3V and 1.8V Power Supply

Sheet: Power ON/OFF Logic

Sheet: UART to USB Bridge

File: Page10.sch Sheet: Servo Header and EEPROM

File: os_baseboard.sch Sheet: / NVIDIA

Id: 1/15 Title: Open Source Educational Baseboard

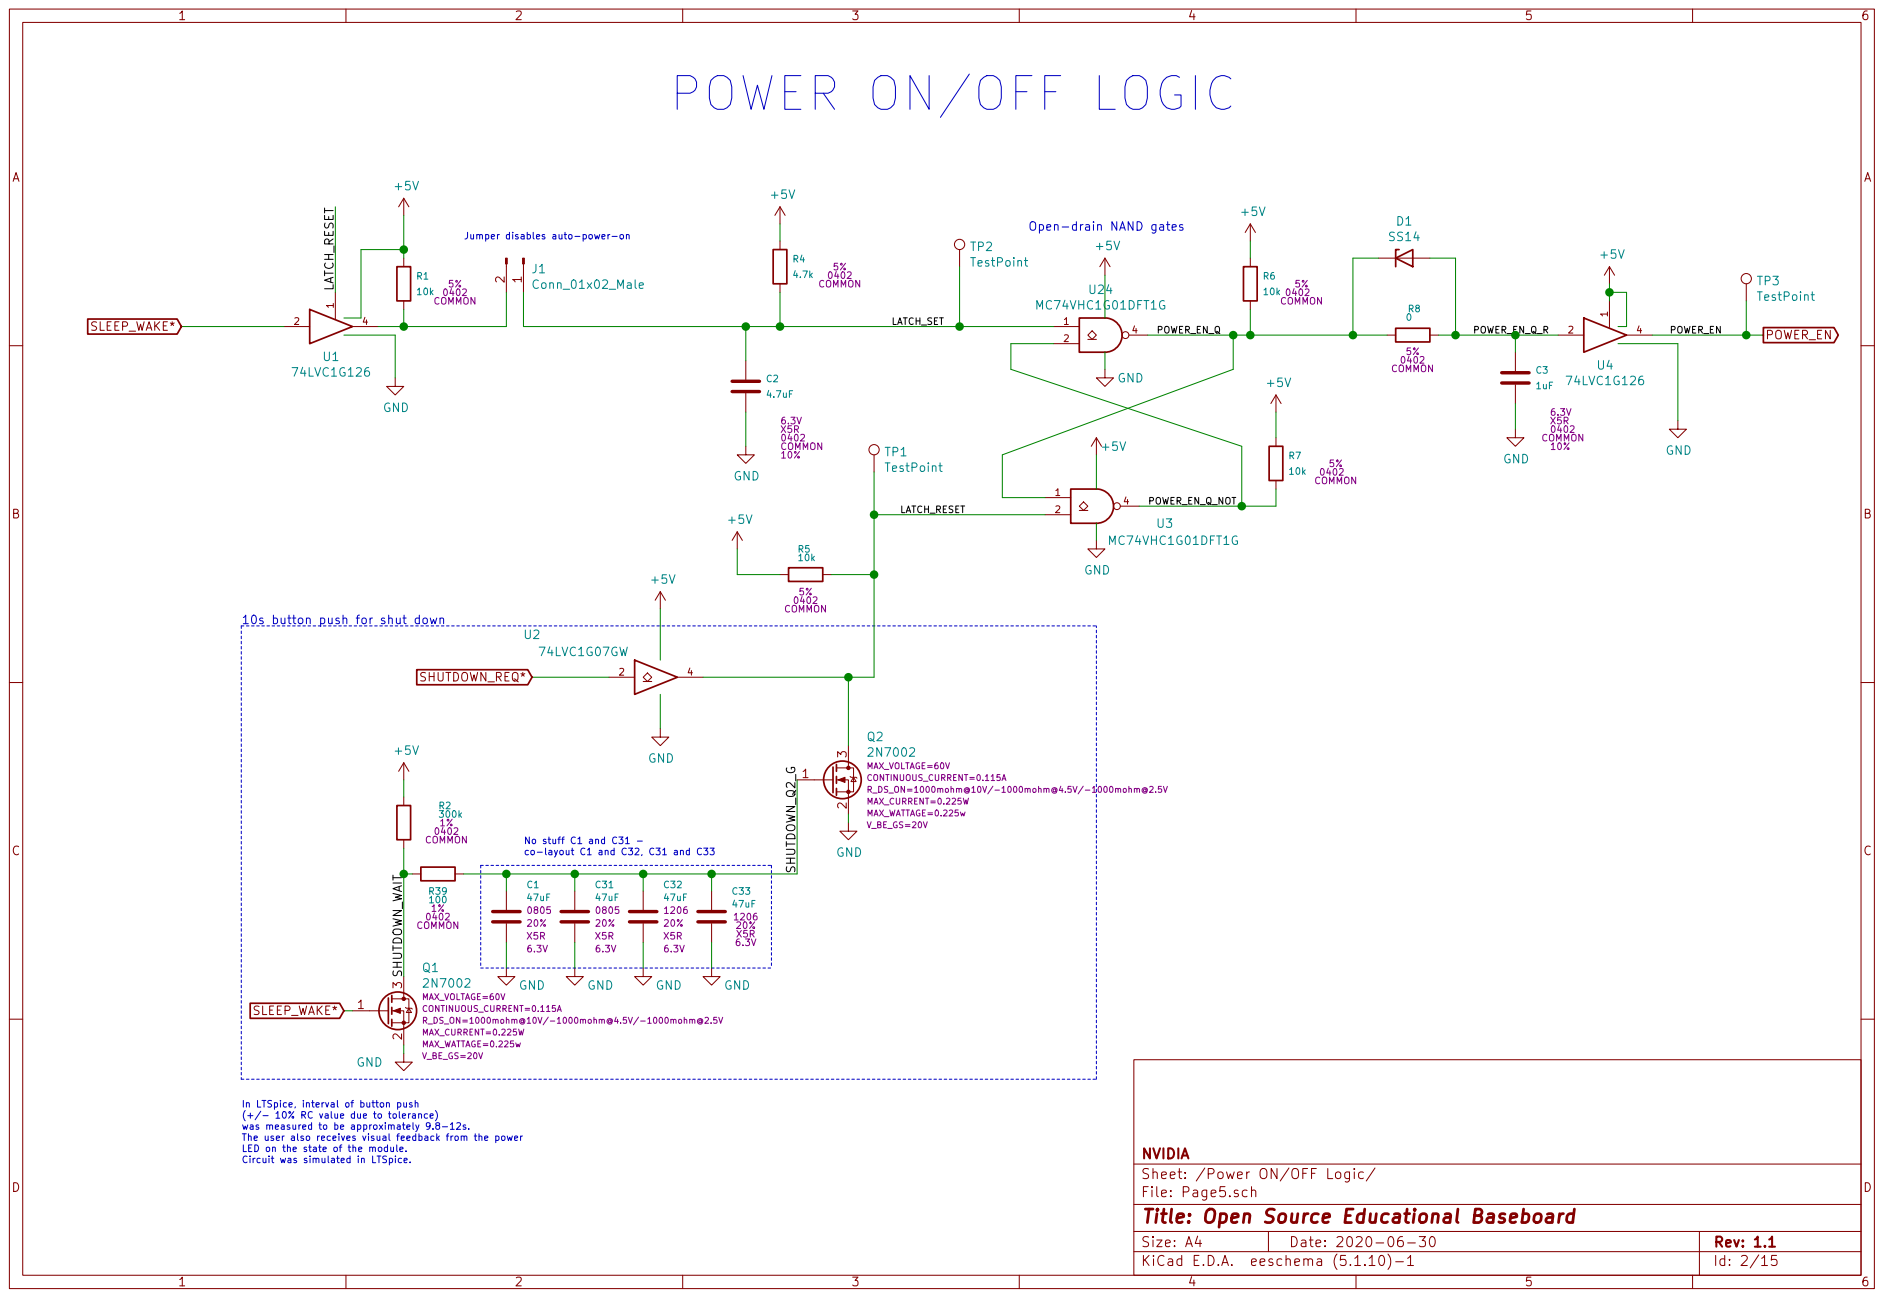
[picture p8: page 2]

Open-drain NAND gates
+5VGND

LATCH_RESET 10s button push for shut down

Sheet: /Power ON/OFF Logic/ NVIDIA

File: Page5.sch
Id: 2/15 Title: Open Source Educational Baseboard

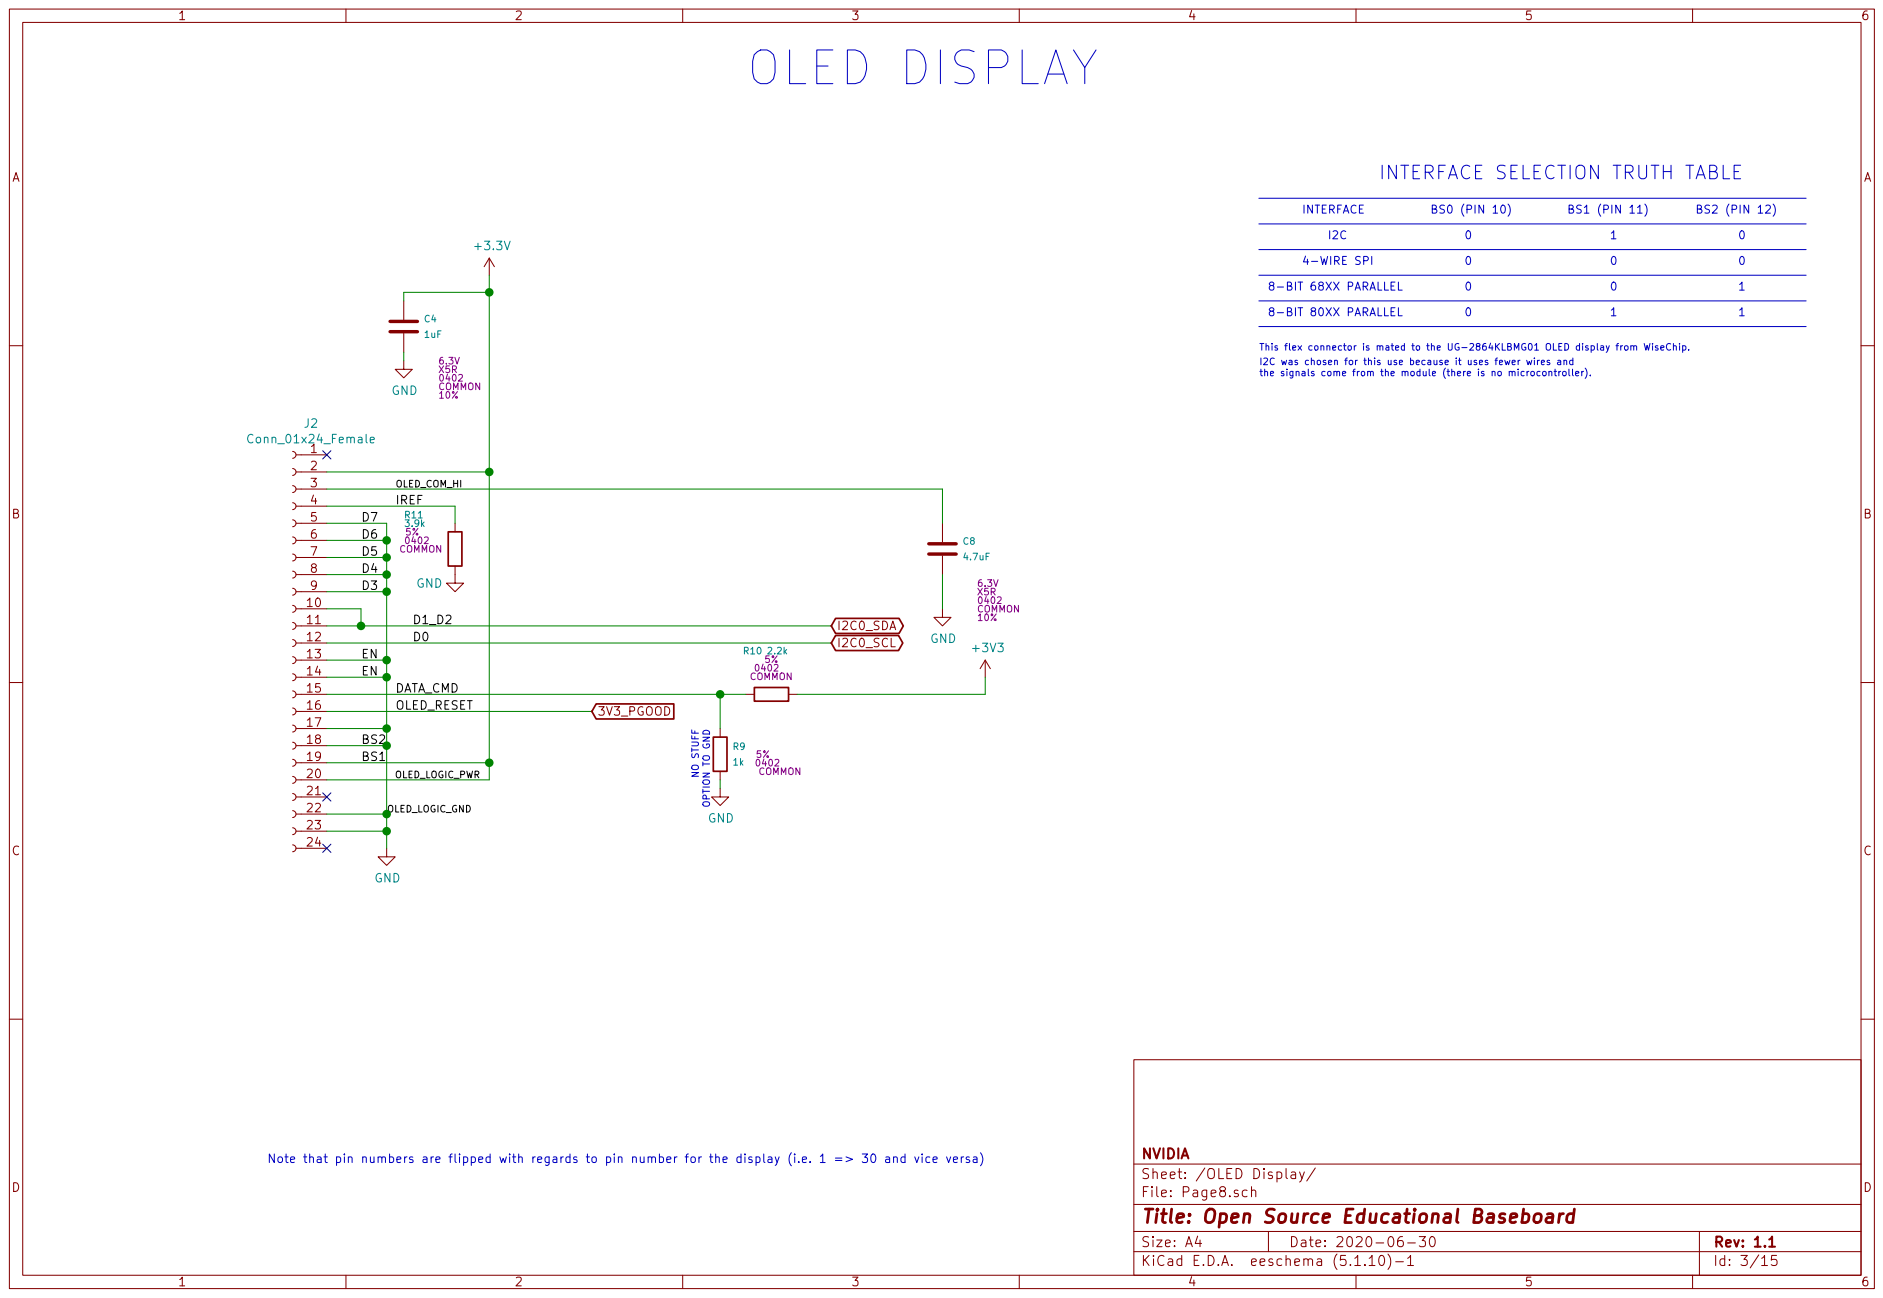
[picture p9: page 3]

0 BS1 (PIN 11) INTERFACE SELECTION TRUTH TABLE

the signals come from the module (there is no microcontroller). 4-WIRE SPI This flex connector is mated to the UG-2864KLBMG01 OLED display from WiseChip.

I2C was chosen for this use because it uses fewer wires and

Sheet: /OLED Display/ NVIDIA

Note that pin numbers are flipped with regards to pin number for the display (i.e. 1 => 30 and vice versa)

File: Page8.sch
Id: 3/15 Title: Open Source Educational Baseboard

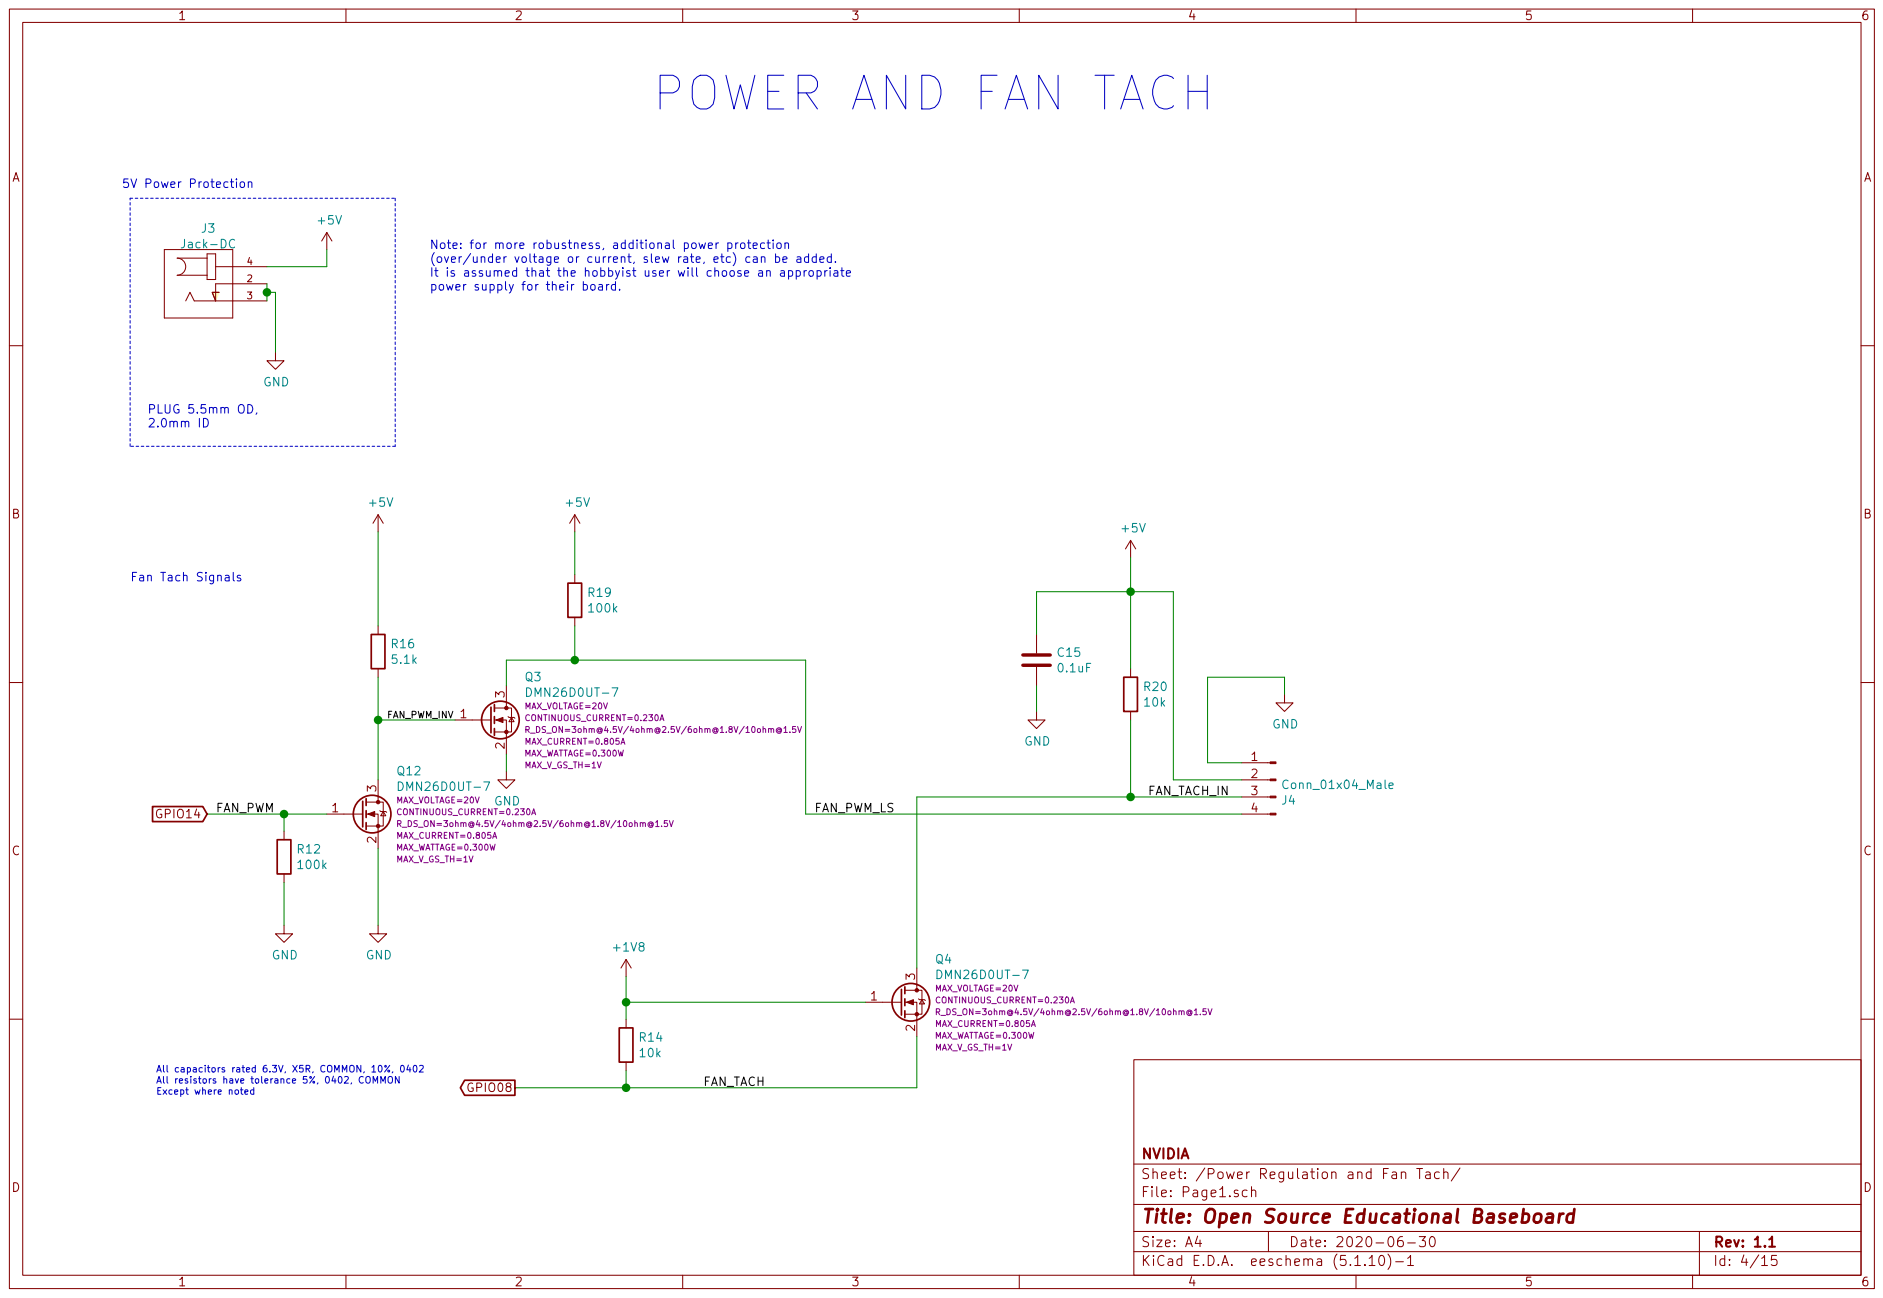
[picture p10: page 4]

Note: for more robustness, additional power protection
(over/under voltage or current, slew rate, etc) can be added.
It is assumed that the hobbyist user will choose an appropriate
power supply for their board.

All capacitors rated 6.3V, X5R, COMMON, 10%, 0402 All resistors have tolerance 5%, 0402, COMMON

Sheet: /Power Regulation and Fan Tach/ NVIDIA

File: Page1.sch
Id: 4/15 Title: Open Source Educational Baseboard

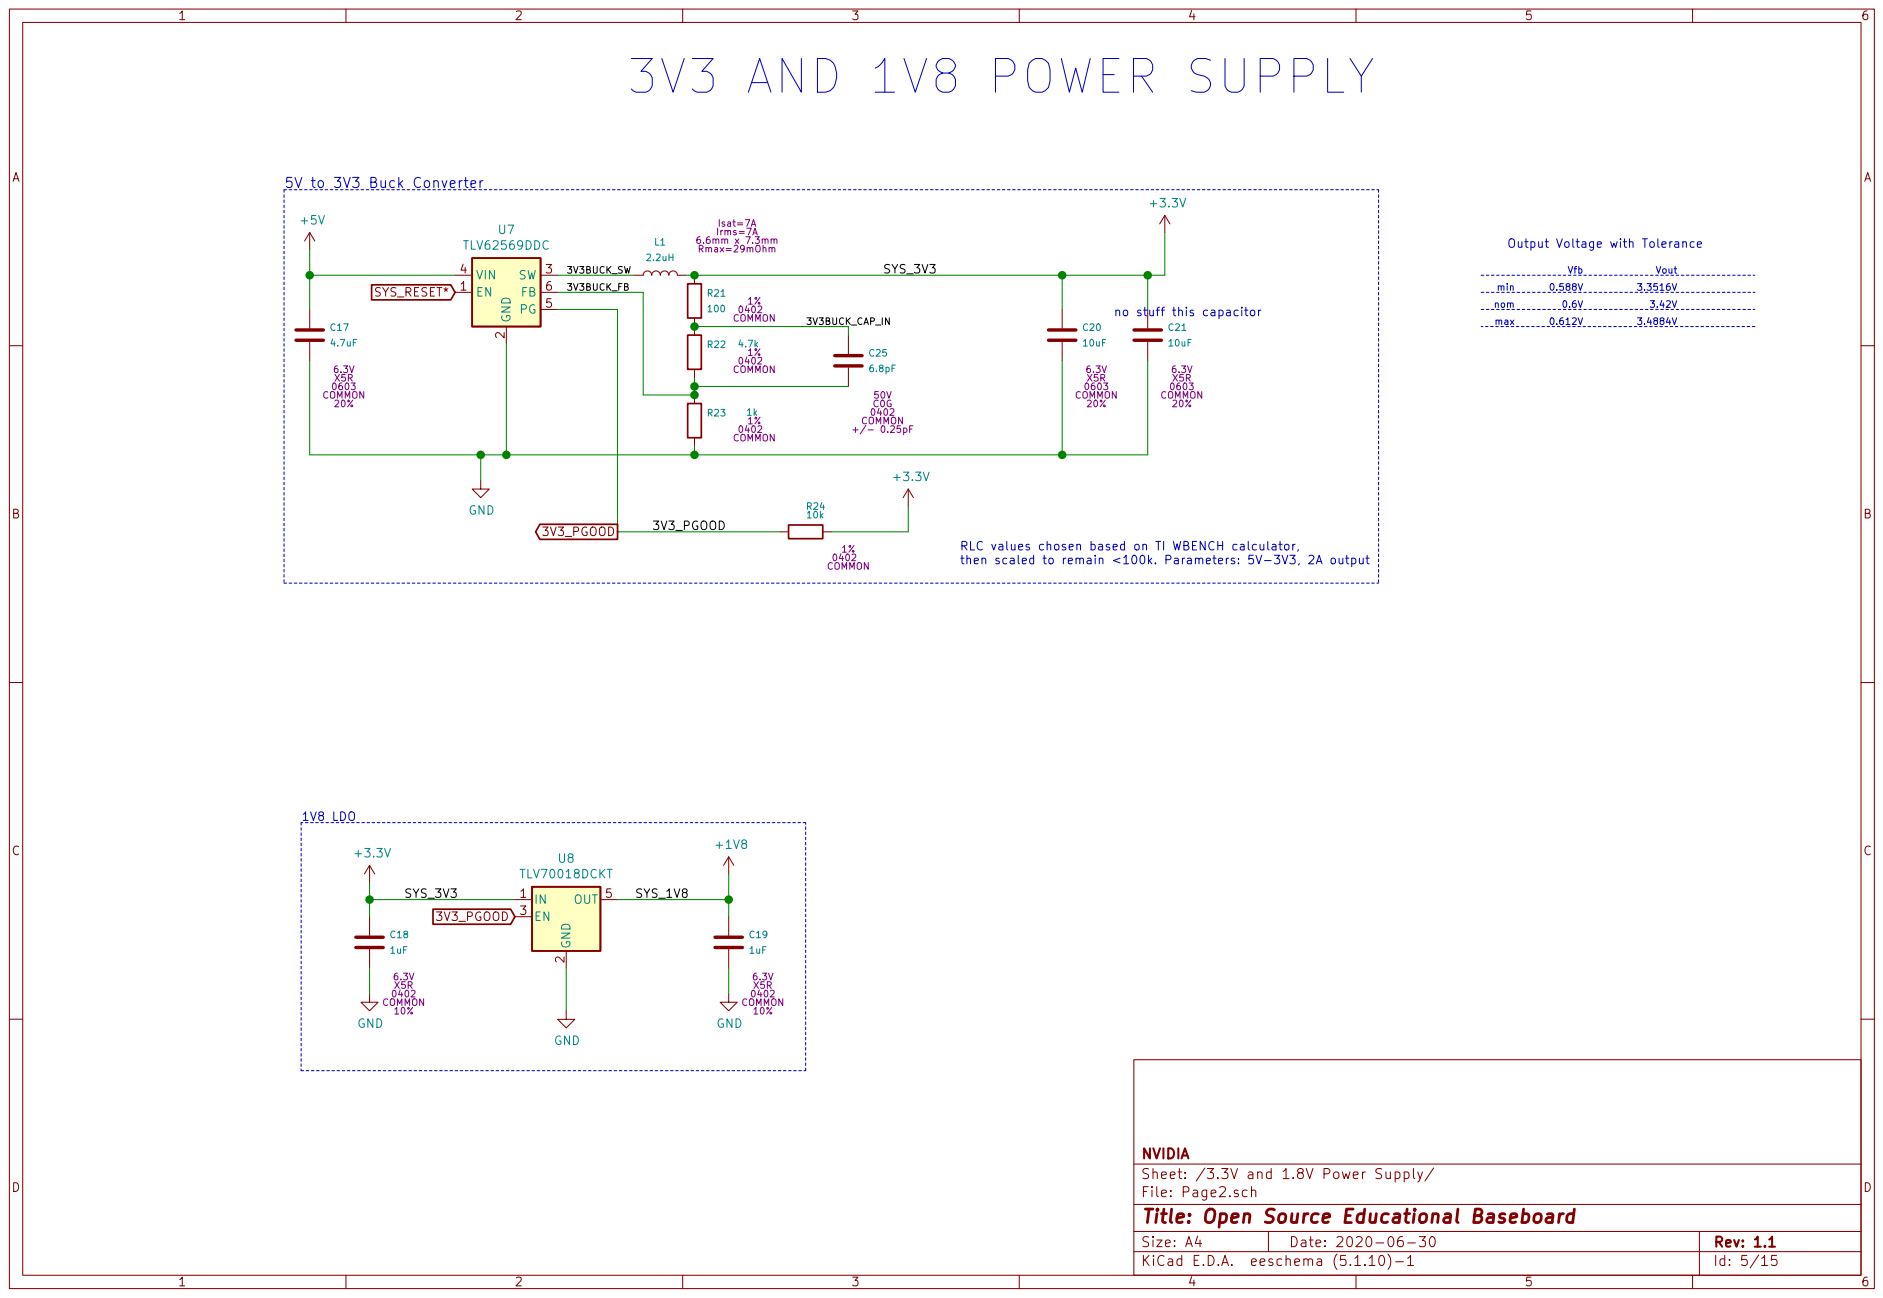
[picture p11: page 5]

2 SW 3 VIN 4 PG 5 FB 6 U7 TLV62569DDC

maxOutput Voltage with Tolerance

Vfb no stuff this capacitor RLC values chosen based on TI WBENCH calculator,

Sheet: /3.3V and 1.8V Power Supply/ NVIDIA

File: Page2.sch
Id: 5/15 Title: Open Source Educational Baseboard

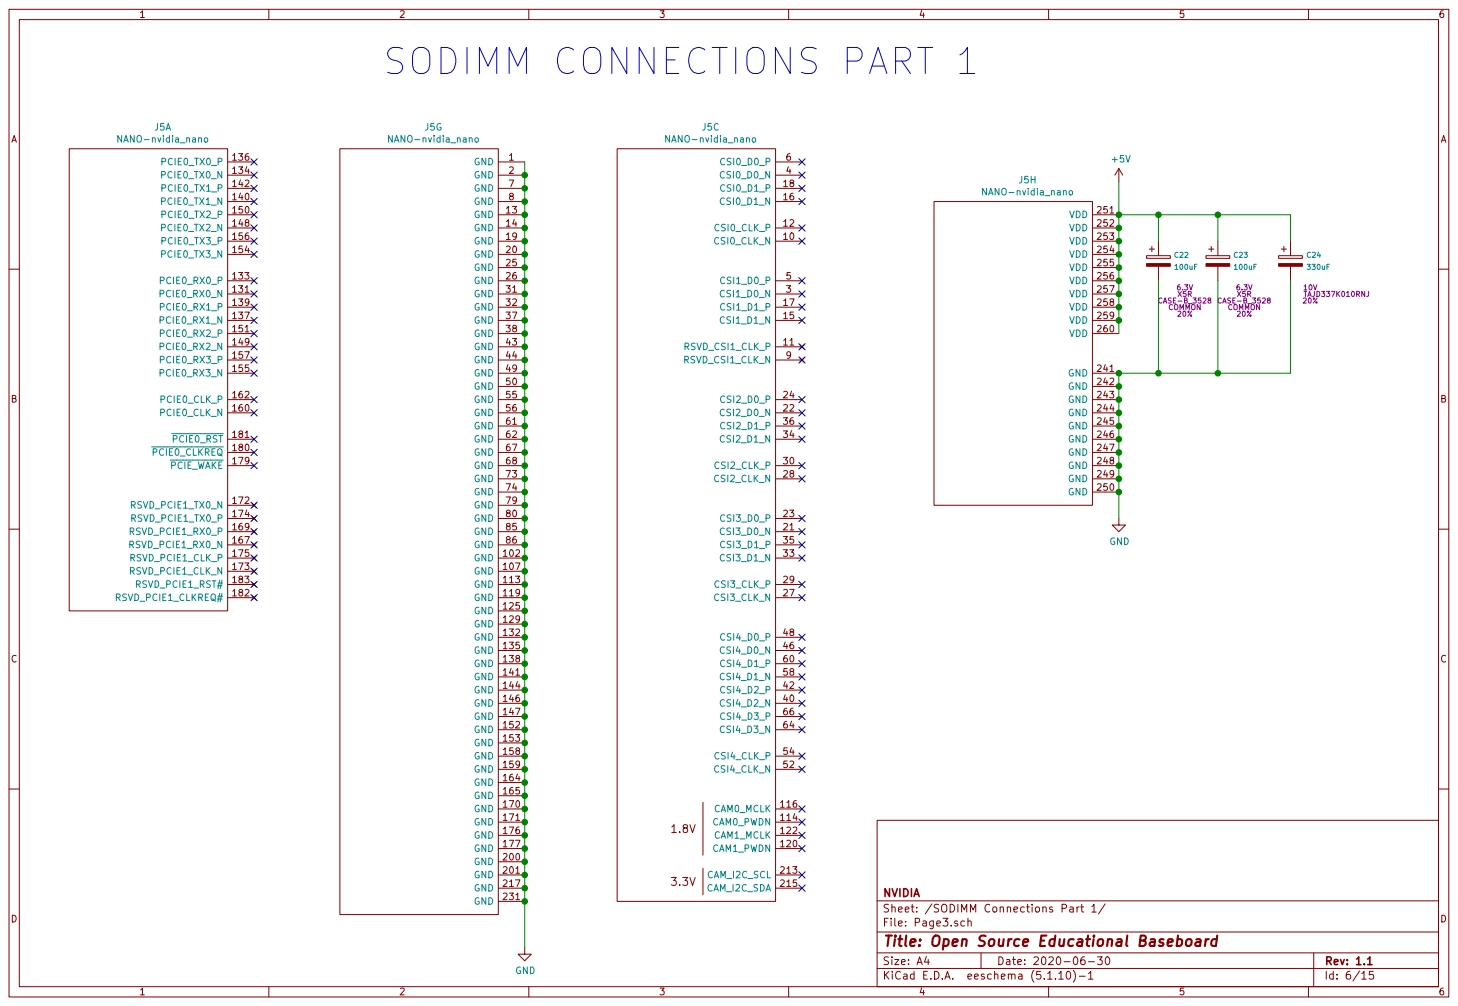
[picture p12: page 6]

File: Page3.sch Sheet: /SODIMM Connections Part 1/ NVIDIA

Id: 6/15 Title: Open Source Educational Baseboard

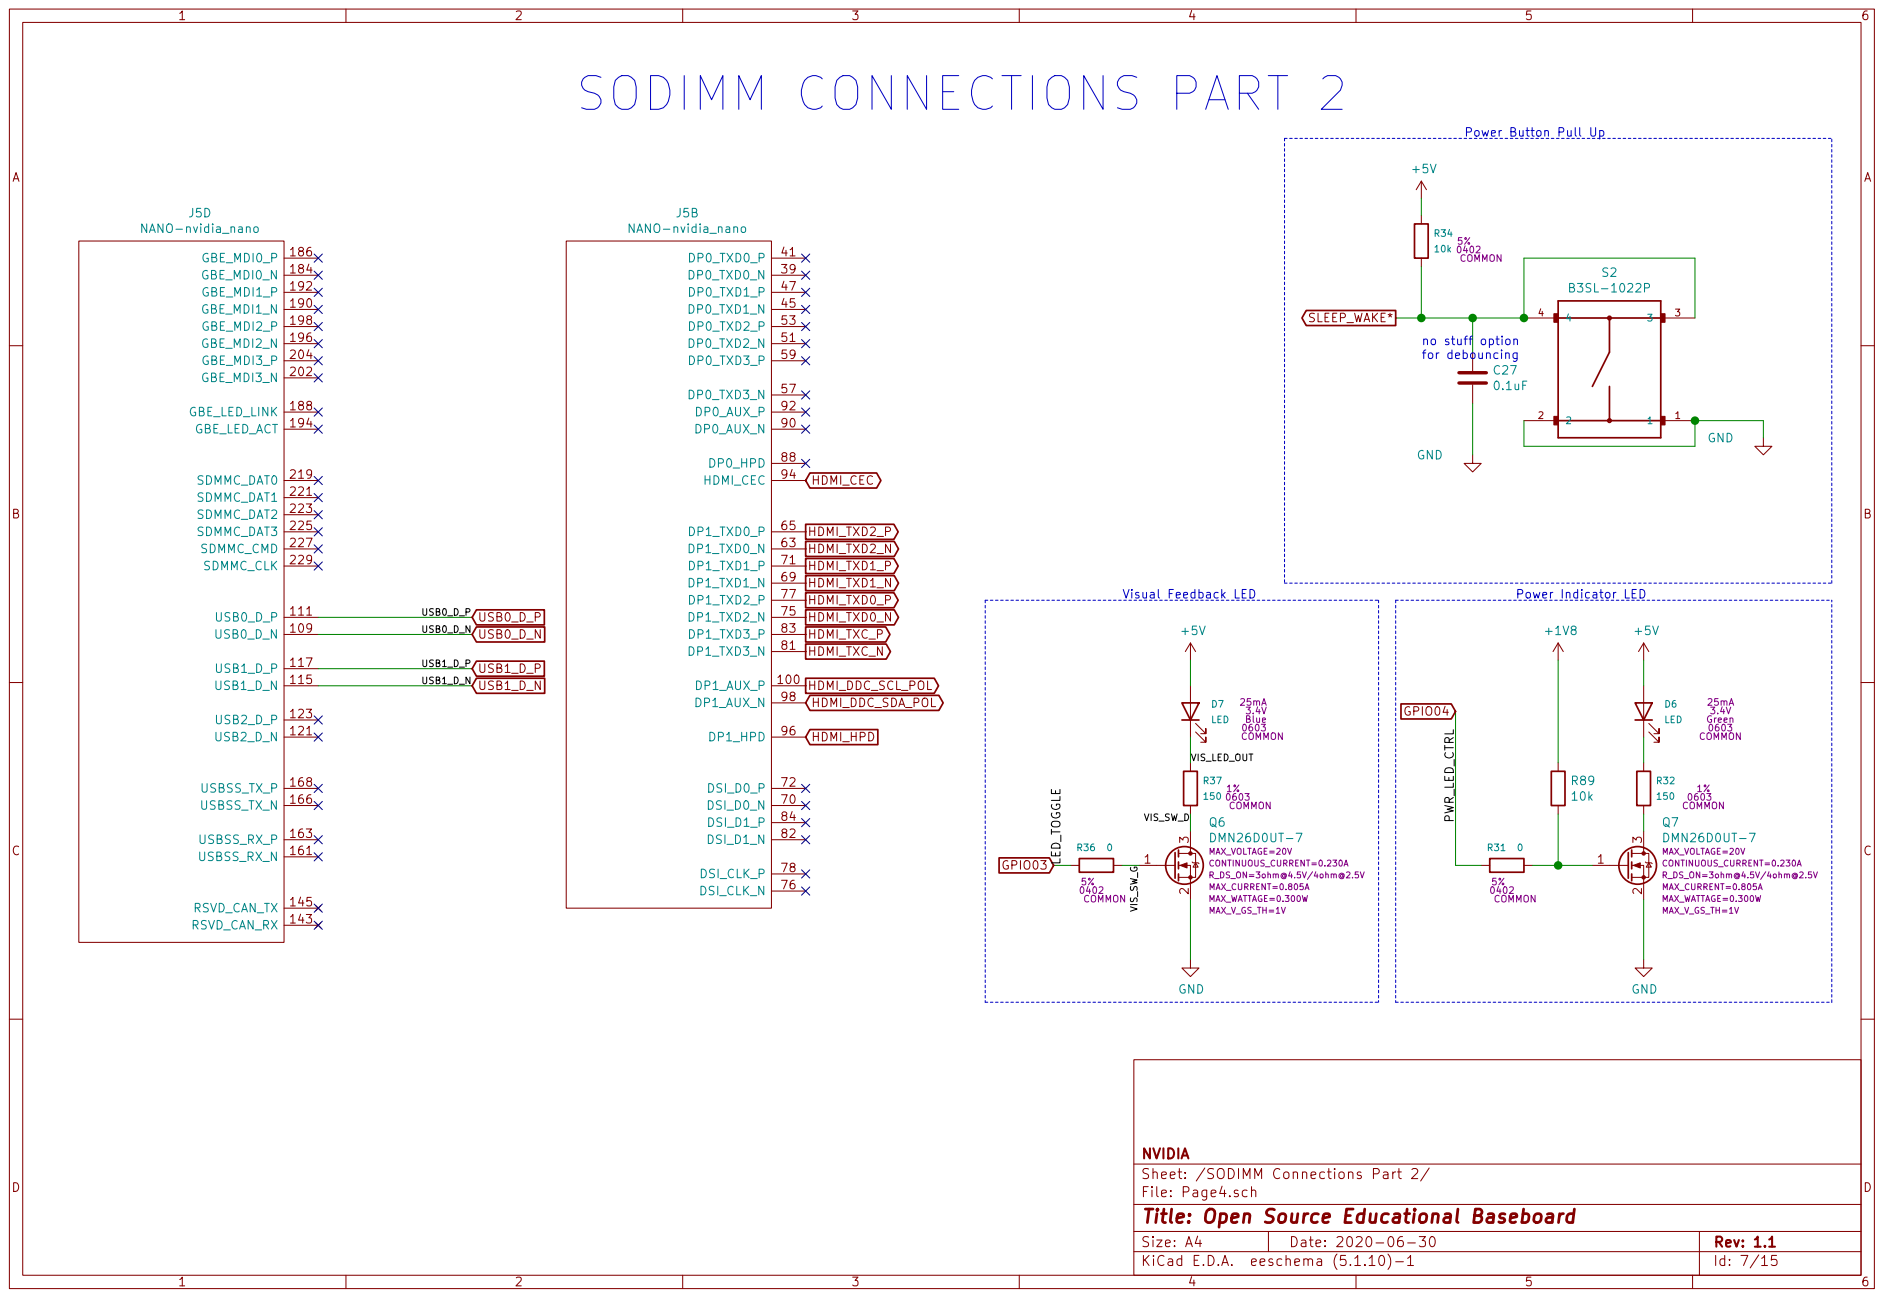
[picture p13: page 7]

for debouncing Power Indicator LED SODIMM CONNECTIONS PART 2

File: Page4.sch Sheet: /SODIMM Connections Part 2/ NVIDIA

Id: 7/15 Title: Open Source Educational Baseboard

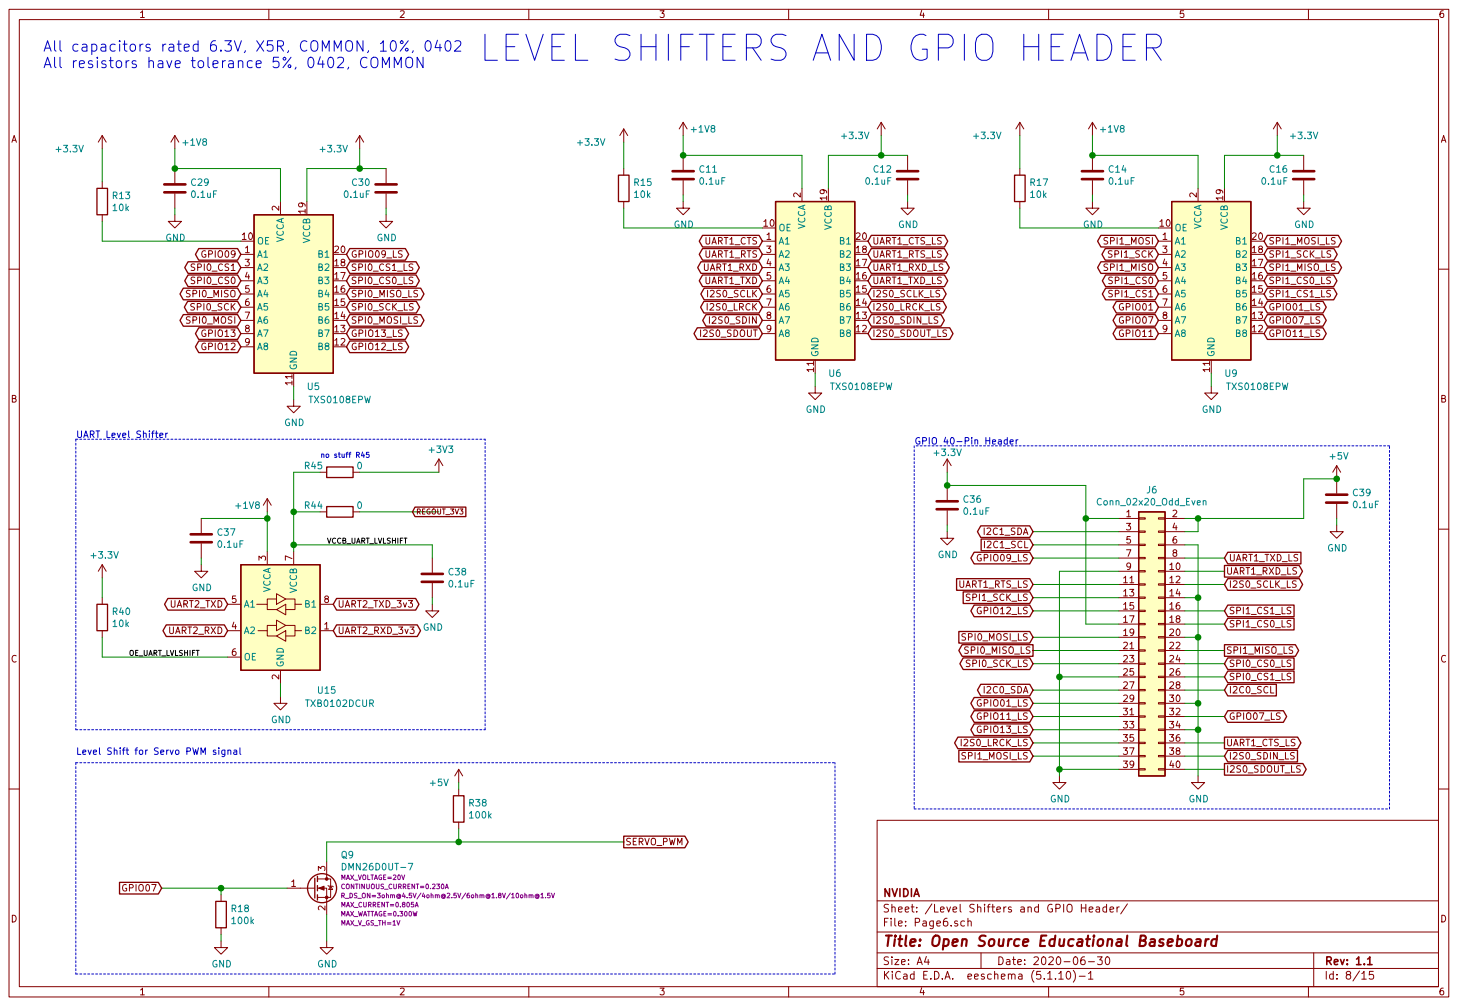
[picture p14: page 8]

GPIO 40-Pin Header All capacitors rated 6.3V, X5R, COMMON, 10%, 0402
All resistors have tolerance 5%, 0402, COMMON

File: Page6.sch Sheet: /Level Shifters and GPIO Header/ NVIDIA

Id: 8/15 Title: Open Source Educational Baseboard

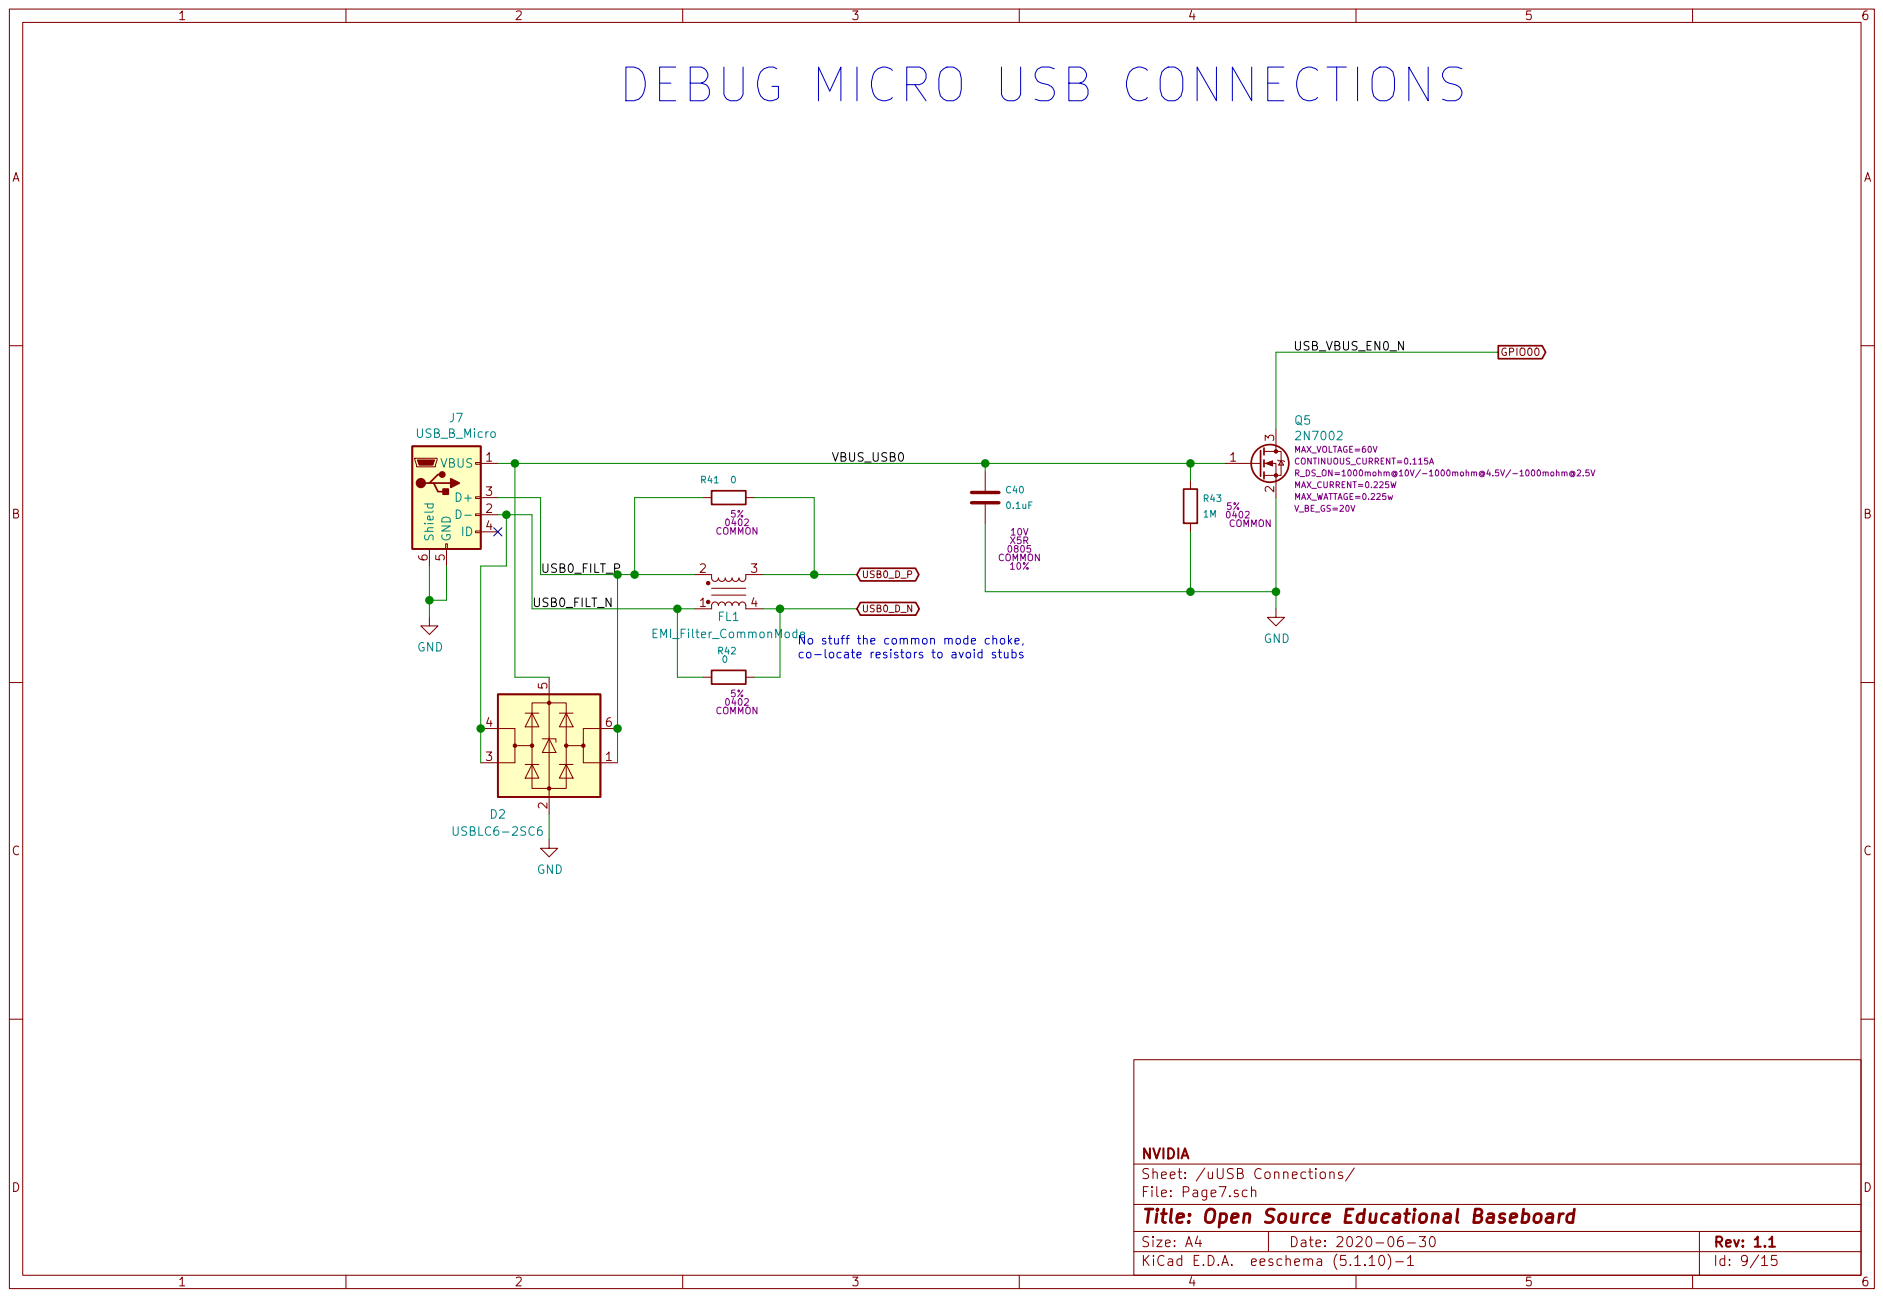
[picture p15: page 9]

File: Page7.sch Sheet: /uUSB Connections/ NVIDIA

Id: 9/15 Title: Open Source Educational Baseboard

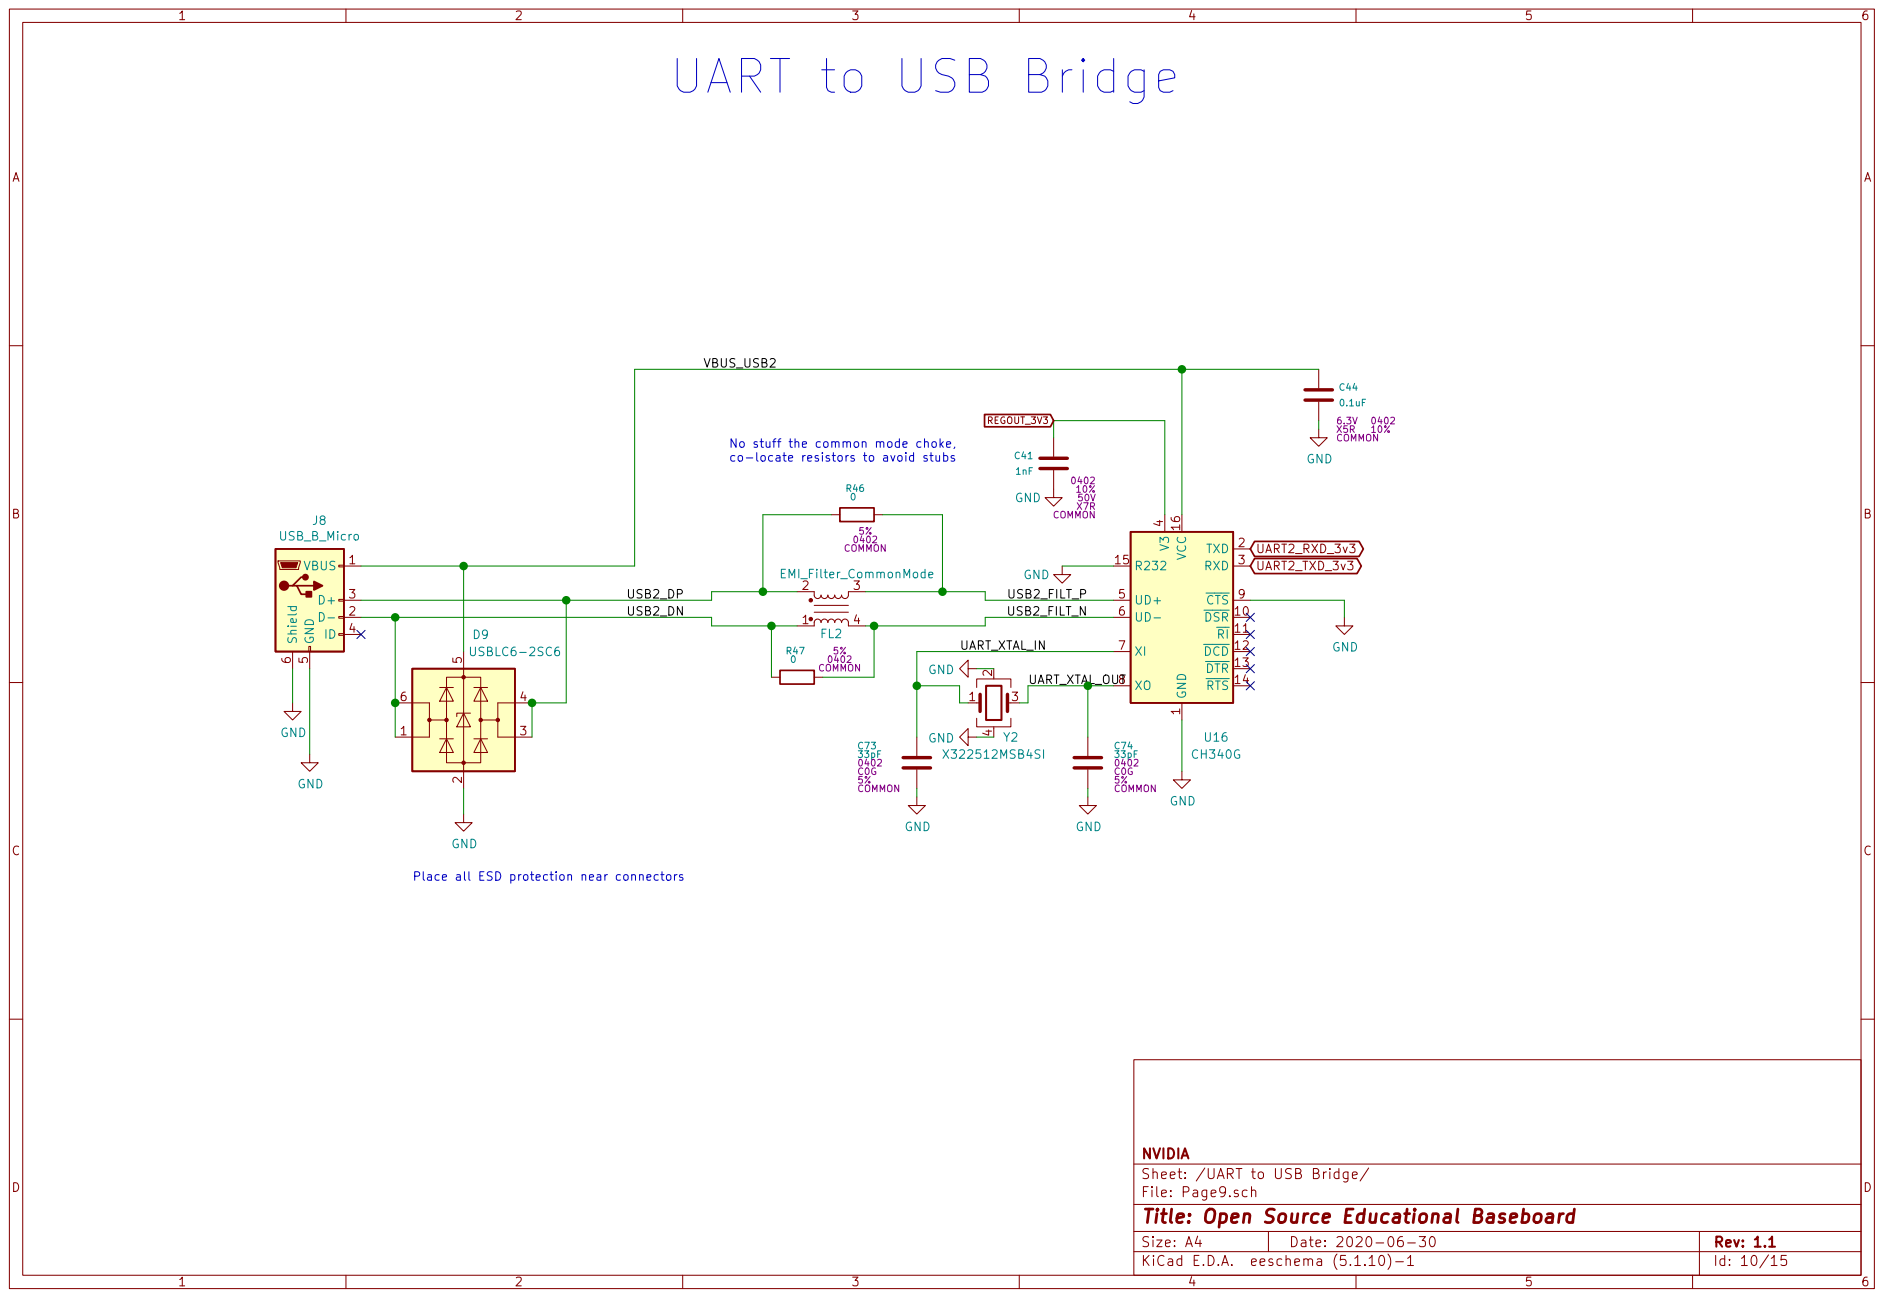
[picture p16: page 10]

UART_XTAL_OUT UART to USB Bridge

No stuff the common mode choke, co-locate resistors to avoid stubs Place all ESD protection near connectors

1 DSR 10 RI 11 DCD 12 DTR 13 RTS 14 R232 15 VCC 16 TXD 2 RXD 3 V3

4 UD+ 5 UD- 6 XI 7 XO 8 CTS 9 U16 CH340G

Sheet: /UART to USB Bridge/ NVIDIA

File: Page9.sch
Id: 10/15 Title: Open Source Educational Baseboard

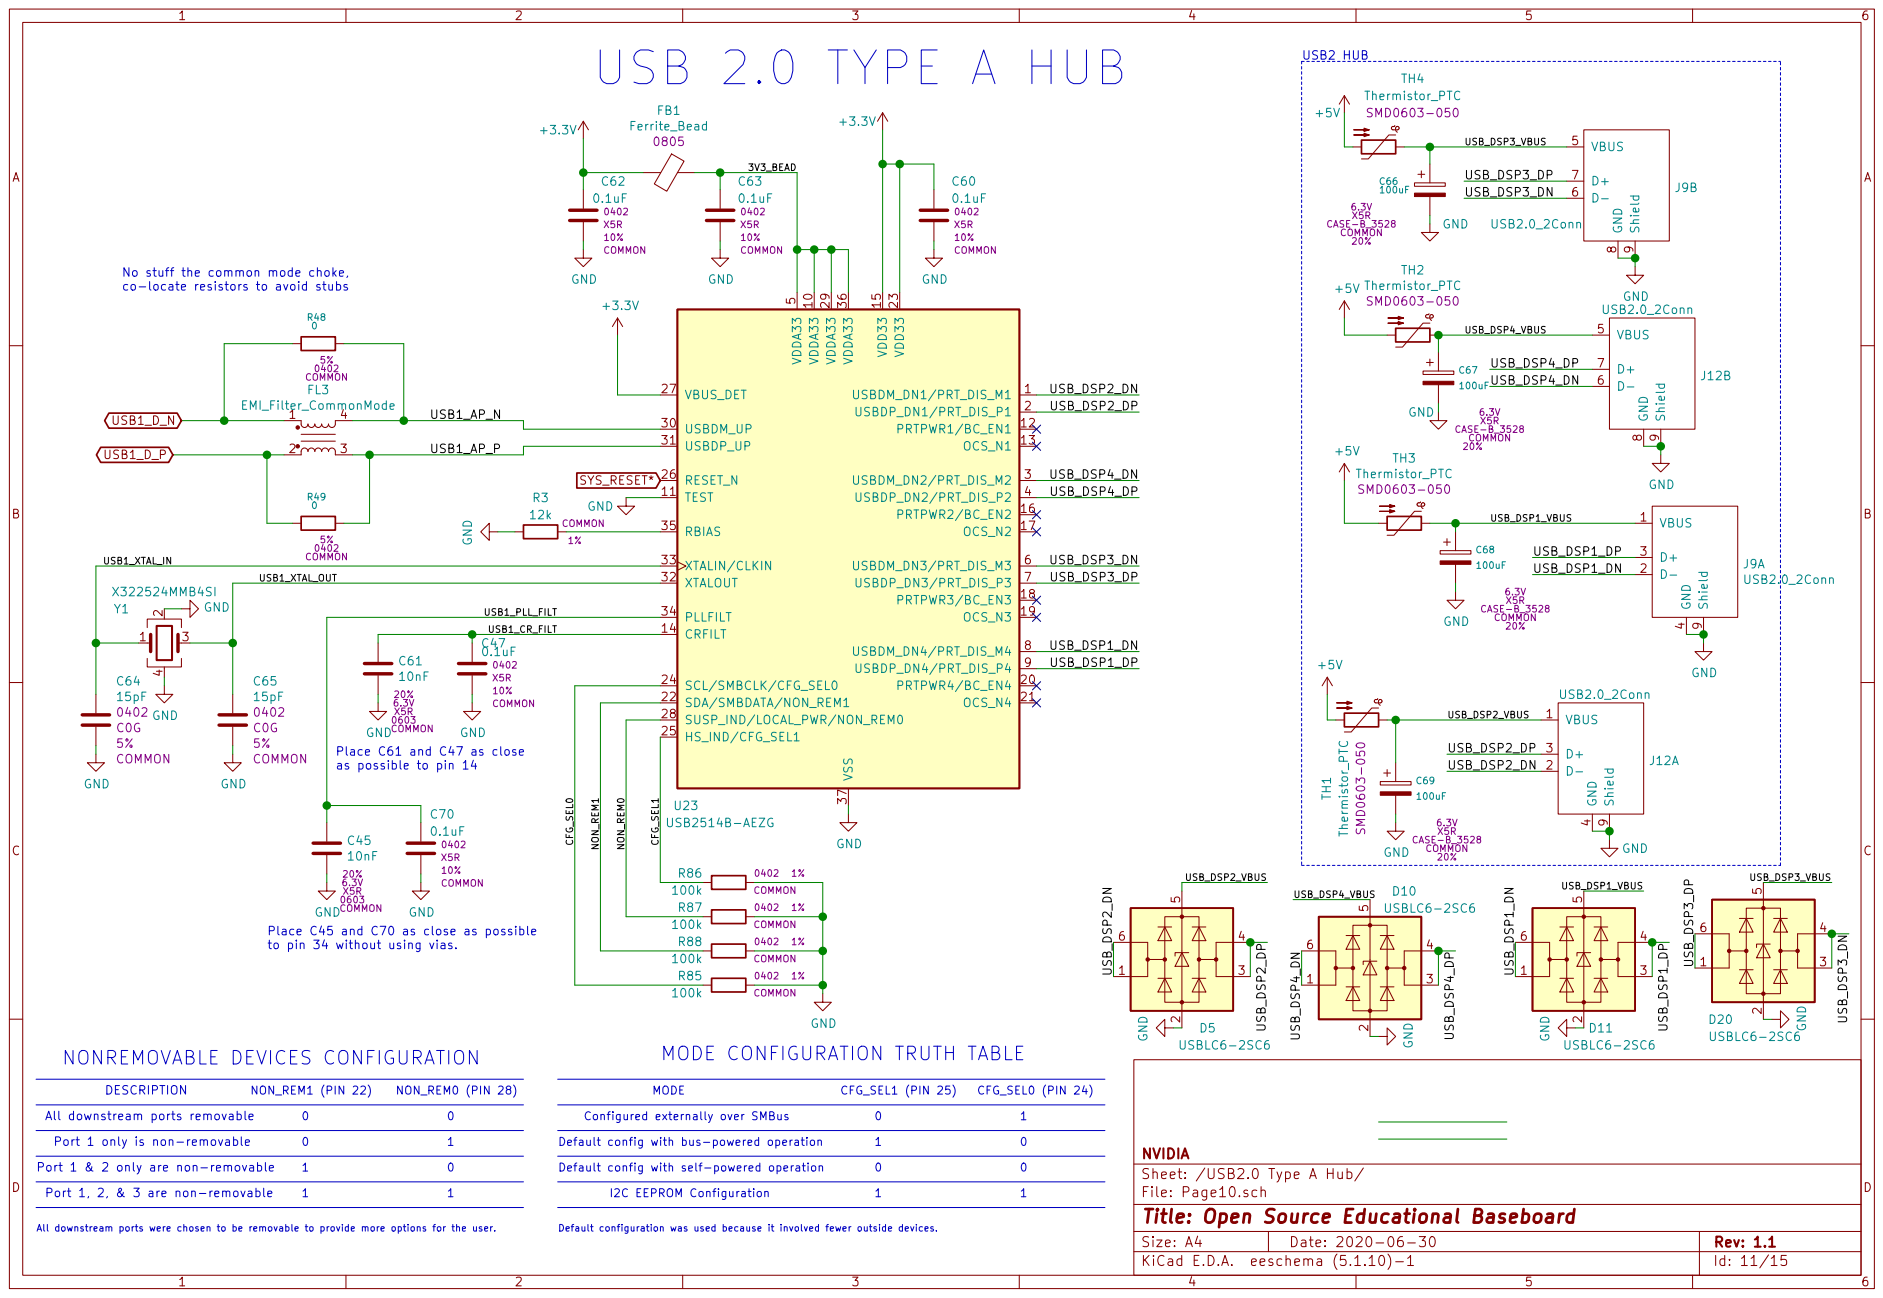
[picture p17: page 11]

All downstream ports were chosen to be removable to provide more options for the user. NONREMOVABLE DEVICES CONFIGURATION

Default config with bus-powered operation Default config with self-powered operation Default configuration was used because it involved fewer outside devices. MODE CONFIGURATION TRUTH TABLE

All downstream ports removable

Sheet: /USB2.0 Type A Hub/ NVIDIA

File: Page10.sch
Id: 11/15 Title: Open Source Educational Baseboard

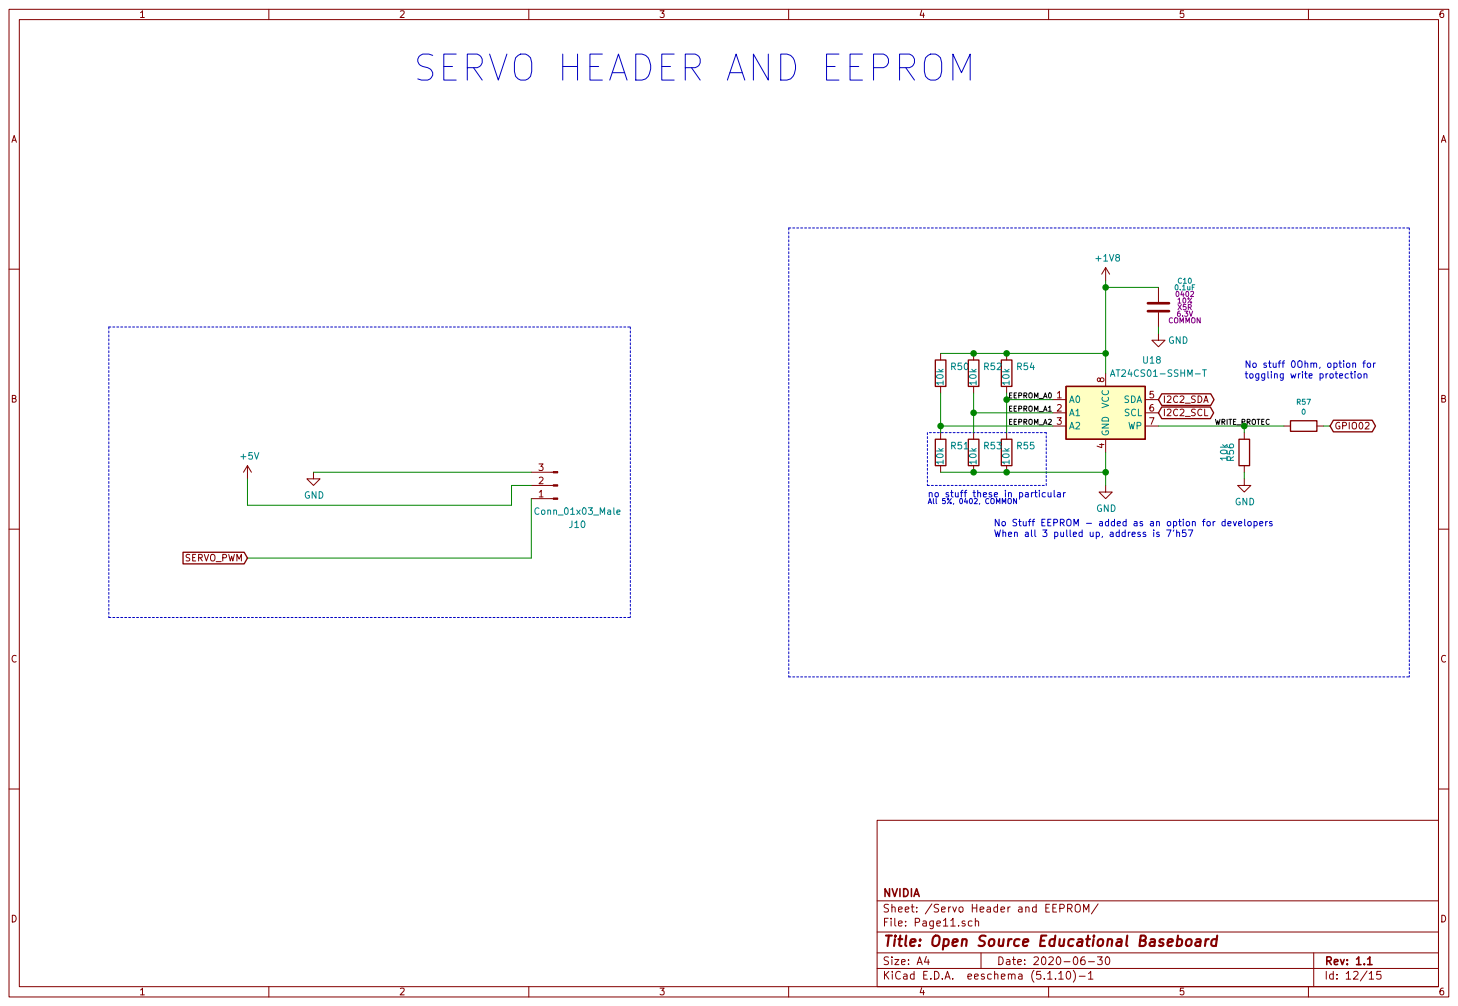
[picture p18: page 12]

EEPROM_A0 EEPROM_A1 EEPROM_A2 SERVO HEADER AND EEPROM

No stuff 0Ohm, option for
toggling write protection

4 SDA 5 SCL 6 WP 7 VCC

no stuff these in particular All 5%, 0402, COMMON

No Stuff EEPROM - added as an option for developers
When all 3 pulled up, address is 7'h57

File: Page11.sch Sheet: /Servo Header and EEPROM/ NVIDIA

Id: 12/15 Title: Open Source Educational Baseboard


I2C2_SCL
I2C2_SDA

File: Page4b.sch Sheet: /SODIMM Connections Part 3/ NVIDIA

Id: 13/15 Title: Open Source Educational Baseboard


File: Page12.sch Sheet: /HDMI Connections Part 1/ R58

Place all ESD protection close to connectors


I (A) R91 chosen so the current limit is 600mA, the minimum
for this load switch, with a tolerance of 1%.
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

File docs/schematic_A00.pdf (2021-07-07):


File: Page2.sch Sheet: SODIMM Connections Part 1 File: Page3.sch Sheet: SODIMM Connections Part 2 File: Page4.sch Sheet: Level Shifters and GPIO Header File: Page6.sch Sheet: uUSB Connections File: Page7.sch
File: Page11.sch Sheet: SODIMM Connections Part 3 File: Page4b.sch Sheet: HDMI Connections Part 1 File: Page12.sch Sheet: HDMI Connections Part 2 File: Page13.sch

Sheet: Power Regulation and Fan Tach

Sheet: 3.3V and 1.8V Power Supply

Sheet: Power ON/OFF Logic

Sheet: UART to USB Bridge

File: Page10.sch Sheet: Servo Header and EEPROM

File: os_baseboard.sch Sheet: / NVIDIA

Id: 1/15 Title: Open Source Educational Baseboard


POWER AND FAN TACH

5V Power Protection Fan Tach Signals

Note: for more robustness, additional power protection
(over/under voltage or current, slew rate, etc) can be added.
It is assumed that the hobbyist user will choose an appropriate
power supply for their board.

All capacitors rated 6.3V, X5R, COMMON, 10%, 0402 All resistors have tolerance 5%, 0402, COMMON

Sheet: /Power Regulation and Fan Tach/ NVIDIA

File: Page1.sch
Id: 4/15 Title: Open Source Educational Baseboard


2 SW 3 VIN 4 PG 5 FB 6 U7 TLV62569DDC

maxOutput Voltage with Tolerance

Vfb no stuff this capacitor RLC values chosen based on TI WBENCH calculator,

Sheet: /3.3V and 1.8V Power Supply/ NVIDIA

File: Page2.sch
Id: 5/15 Title: Open Source Educational Baseboard


NANO-nvidia_nano SODIMM CONNECTIONS PART 1

File: Page3.sch Sheet: /SODIMM Connections Part 1/ NVIDIA

Id: 6/15 Title: Open Source Educational Baseboard


Power Button Pull Up

File: Page4.sch Sheet: /SODIMM Connections Part 2/ NVIDIA

Id: 7/15 Title: Open Source Educational Baseboard


File: Page4b.sch Sheet: /SODIMM Connections Part 3/ NVIDIA

Id: 13/15 Title: Open Source Educational Baseboard


POWER ON/OFF LOGIC

Jumper disables auto-power-on

Open-drain NAND gates
+5VGND

In LTSpice, interval of button push (+/- 10% RC value due to tolerance) was measured to be approximately 9.8-12s. The user also receives visual feedback from the power LED on the state of the module. Circuit was simulated in LTSpice.

Sheet: /Power ON/OFF Logic/ NVIDIA

File: Page5.sch
Id: 2/15 Title: Open Source Educational Baseboard


GPIO 40-Pin Header All capacitors rated 6.3V, X5R, COMMON, 10%, 0402
All resistors have tolerance 5%, 0402, COMMON

VCCB_UART_LVLSHIFT OE_UART_LVLSHIFT UART Level Shifter Level Shift for Servo PWM signal

File: Page6.sch Sheet: /Level Shifters and GPIO Header/ NVIDIA

Id: 8/15 Title: Open Source Educational Baseboard


File: Page7.sch Sheet: /uUSB Connections/ NVIDIA

Id: 9/15 Title: Open Source Educational Baseboard


the signals come from the module (there is no microcontroller). INTERFACE SELECTION TRUTH TABLE

3-WIRE SPI 4-WIRE SPI 8-BIT 68XX PARALLEL

This flex connector is mated to the VG-2864KSWEG01 OLED display from WiseChip. The QG-2864KLBEG01 is also pin-compatible.

I2C was chosen for this use because it uses fewer wires and

Sheet: /OLED Display/ NVIDIA

File: Page8.sch
Id: 3/15 Title: Open Source Educational Baseboard


1 DSR 10 RI 11 DCD 12 DTR 13 RTS 14 R232 15 VCC 16 TXD 2 RXD 3 V3

4 UD+ 5 UD- 6 XI 7 XO 8 CTS 9 U16 CH340G

Sheet: /UART to USB Bridge/ NVIDIA

File: Page9.sch
Id: 10/15 Title: Open Source Educational Baseboard


USB1_XTAL_OUT No stuff the common mode choke, co-locate resistors to avoid stubs

Configured externally over SMBus Default configuration was used because it involved fewer outside devices. MODE CONFIGURATION TRUTH TABLE

Sheet: /USB2.0 Type A Hub/ NVIDIA

Port 1, 2, & 3 are non-removable Port 1 & 2 only are non-removable

File: Page10.sch
Id: 11/15 Title: Open Source Educational Baseboard


EEPROM_A0 EEPROM_A1 EEPROM_A2 SERVO HEADER AND EEPROM

No stuff 0Ohm, option for
toggling write protection

4 SDA 5 SCL 6 WP 7 VCC

no stuff these in particular All 5%, 0402, COMMON

No Stuff EEPROM - added as an option for developers
When all 3 pulled up, address is 7'h57

File: Page11.sch Sheet: /Servo Header and EEPROM/ NVIDIA

Id: 12/15 Title: Open Source Educational Baseboard


No stuff the common mode choke, co-locate resistors to avoid stubs

Place all ESD protection close to connectors
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

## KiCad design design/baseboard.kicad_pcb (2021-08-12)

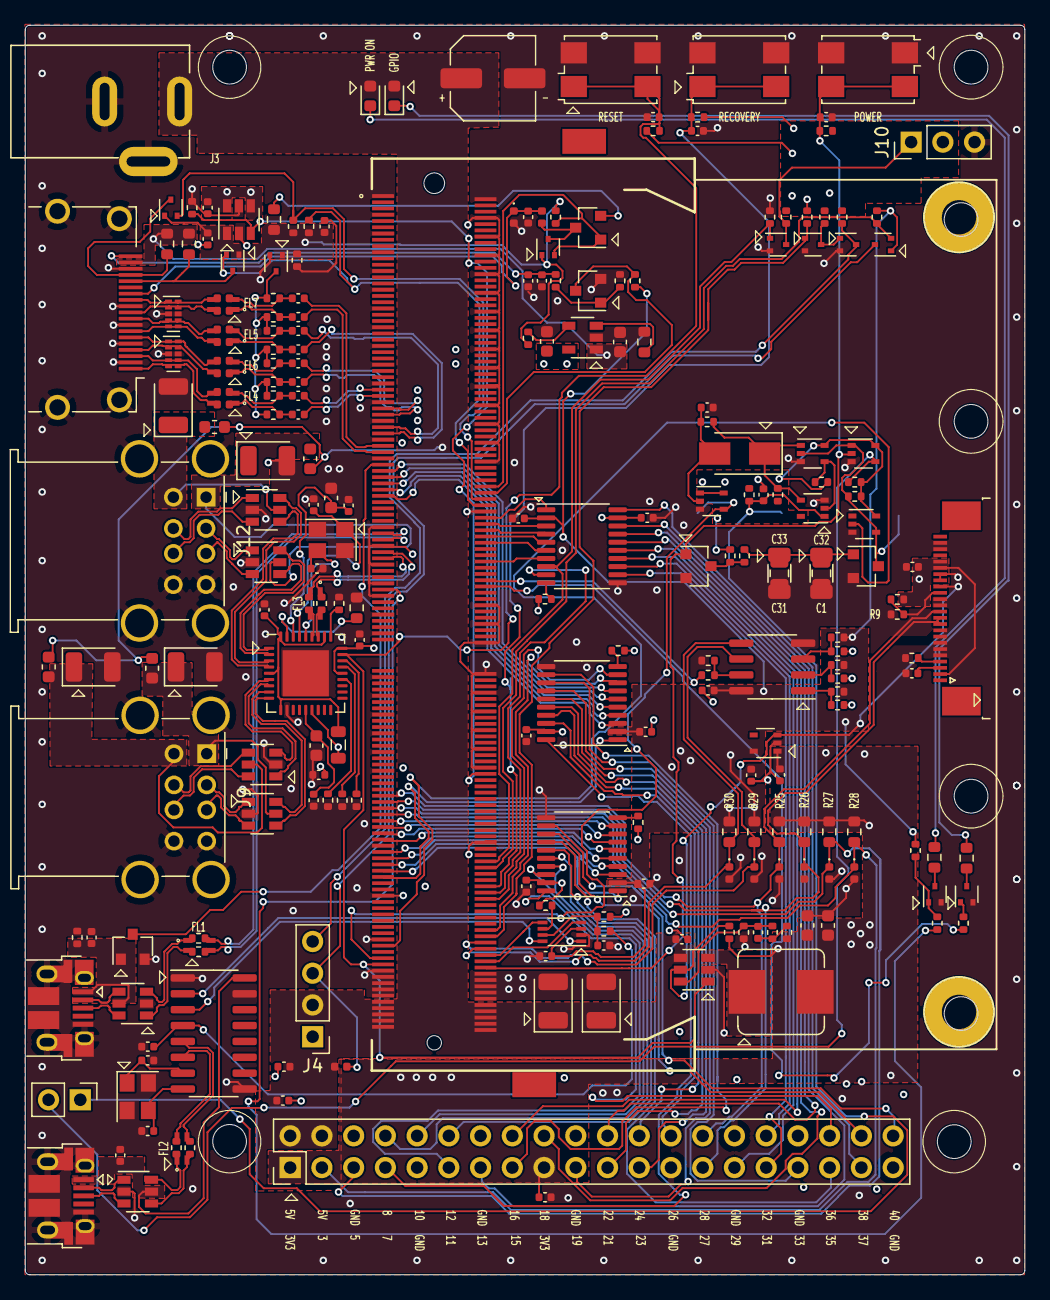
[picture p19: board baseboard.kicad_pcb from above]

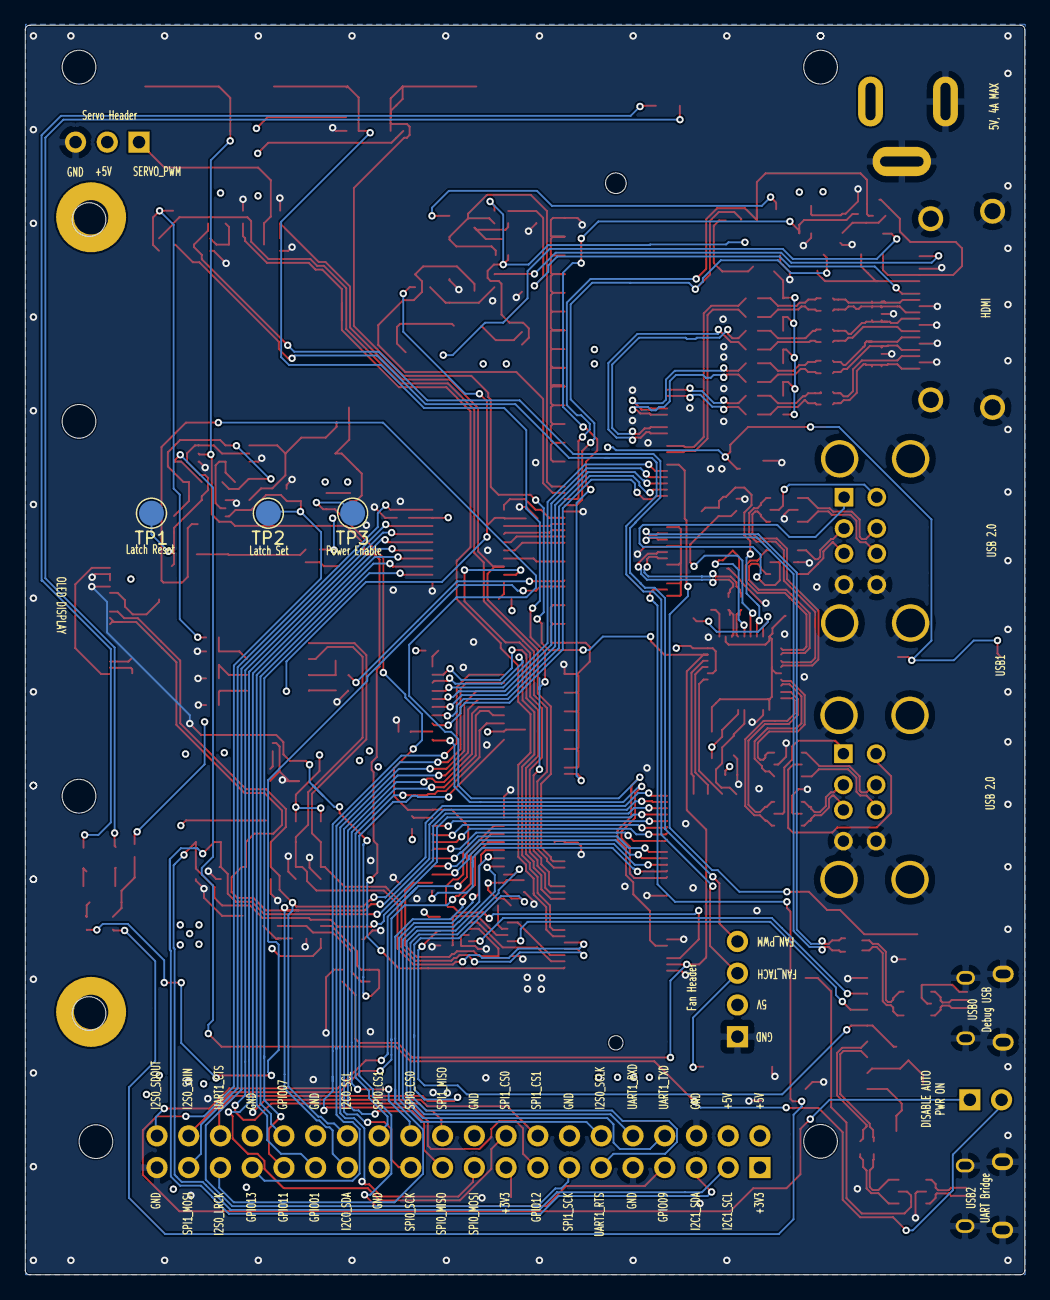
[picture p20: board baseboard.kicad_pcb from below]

Board: 4 copper layers, 80.0 x 100.0 mm, 240 parts (3 on the bottom side), 187 nets.

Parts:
C1, C31: 47uF; C_0805_2012Metric
C2, C8, C17: 4.7uF; C_0402_1005Metric
C3, C4, C18, C19: 1uF; C_0402_1005Metric
C10, C11, C12, C13, C14, C15, C16, C26, C27, C28, C29, C30, C36, C37, C38, C39, C40, C44, C46, C47, C48, C49, C50, C51, C52, C53, C54, C55, C56, C59, C60, C62, C63, C70: 0.1uF; C_0402_1005Metric
C20, C21, C72: 10uF; C_0603_1608Metric
C22, C23, C66, C67, C68, C69: 100uF; CP_EIA-3528-12_Kemet-T
C24: 330uF; C_Elec_6.3x7.7
C25: 6.8pF; C_0402_1005Metric
C32, C33: 47uF; C_1206_3216Metric
C41: 1nF; C_0402_1005Metric
C45, C61: 10nF; C_0603_1608Metric
C57, C58, C64, C65: 15pF; C_0402_1005Metric
C71: 0.1uF; C_0603_1608Metric
C73, C74: 33pF; C_0402_1005Metric
D1: SS14; D_SMA
D2, D5, D9, D10, D11, D20: USBLC6-2SC6; SOT-23-6
D4: BAS70-05; SOT-23
D6, D7: LED; LED_0603_1608Metric
D8, D12, D13, D14, D15, D16, D17: TPD1E10B06DPYR; D_0402_1005Metric
D18, D19: TPD4E02B04DQAR; USON-10_2.5x1.0mm_P0.5mm
FB1: Ferrite_Bead; L_0805_2012Metric
FL1, FL2, FL3, FL4, FL5, FL6, FL7: EMI_Filter_CommonMode; FIL_ACM2012-201-2P-T001
J1: Conn_01x02_Male; PinHeader_1x02_P2.54mm_Vertical
J2: Conn_01x24_Female; TE_2-1734839-4_1x24-1MP_P0.5mm_Horizontal
J3: Jack-DC; NINIGI_DC-005
J4: Conn_01x04_Male; PinHeader_1x04_P2.54mm_Vertical
J5: NANO-nvidia_nano; SODIMM-DDR4_8mm-NANO
J6: Conn_02x20_Odd_Even; PinHeader_2x20_P2.54mm_Vertical
J7, J8: USB_B_Micro; USB_Micro-B_Amphenol_10103594-0001LF_Horizontal
J9, J12: USB2.0_2Conn; USB_A_Wuerth_61400826021_Horizontal_Stacked
J10: Conn_01x03_Male; PinHeader_1x03_P2.54mm_Vertical
J11: HDMI_A; HDMI_A_Amphenol_10029449-111
L1: 2.2uH; L_Bourns_SRP7028A_7.3x6.6mm
L2: 1.2nH; L_0402_1005Metric
Q1, Q2, Q5: 2N7002; SOT-23
Q3, Q4, Q6, Q7, Q9, Q10, Q11, Q12, Q13, Q14: DMN26D0UT-7; SOT-523
Q8: MMBT3904; SOT-23
R1, R5, R6, R7, R13, R14, R15, R17, R20, R24, R33, R34, R35, R40, R50, R51, R52, R53, R54, R55, R56, R58, R71, R72, R79, R89, R90: 10k; R_0402_1005Metric
R2: 300k; R_0402_1005Metric
R3: 12k; R_0603_1608Metric
R4, R22: 4.7k; R_0402_1005Metric
R8, R31, R36, R41, R42, R44, R45, R46, R47, R48, R49, R57, R67, R68, R69, R70, R73, R74, R75, R76: 0; R_0402_1005Metric
R9, R23: 1k; R_0402_1005Metric
R10: 2.2k; R_0402_1005Metric
R11: 3.9k; R_0402_1005Metric
R12, R18, R19, R38, R82, R83, R84, R85, R86, R87, R88: 100k; R_0402_1005Metric
R16: 5.1k; R_0402_1005Metric
R21, R39: 100; R_0402_1005Metric
R25, R26, R27, R28, R29, R30: 2.2k; R_0603_1608Metric
R32, R37: 150; R_0603_1608Metric
R43: 1M; R_0402_1005Metric
R59, R60, R61, R62, R63, R64, R65, R66: 510; R_0402_1005Metric
R77, R78: 1.8k; R_0603_1608Metric
R80: 36k; R_0603_1608Metric
R81: 120k; R_0402_1005Metric
R91: 11k; R_0603_1608Metric
S1, S2, S3: B3SL-1022P; Crystal_SMD_7050-4Pin_7.0x5.0mm
TH1, TH2, TH3, TH4: Thermistor_PTC; Fuse_0603_1608Metric
TP1, TP2, TP3: TestPoint; TestPoint_Pad_D2.0mm
U1, U4: 74LVC1G126; SOT-353_SC-70-5
U2: 74LVC1G07GW; SOT-353_SC-70-5
U3, U24: MC74VHC1G01DFT1G; SOT-353_SC-70-5
U5, U6, U9: TXS0108EPW; TSSOP-20_4.4x6.5mm_P0.65mm
U7: TLV62569DDC; SOT-23-6
U8: TLV70018DCKT; SOT-353_SC-70-5
U10: MT9700; SOT-23-5
U15: TXB0102DCUR; VSSOP-8_2.3x2mm_P0.5mm
U16: CH340G; SOIC-16_3.9x9.9mm_P1.27mm
U18: AT24CS01-SSHM-T; SOIC-8_3.9x4.9mm_P1.27mm
U22: AP2281-3WG-7; SOT-23-6
U23: USB2514B-AEZG; QFN-36-1EP_6x6mm_P0.5mm_EP3.7x3.7mm
Y1: X322524MMB4SI; Crystal_SMD_3225-4Pin_3.2x2.5mm
Y2: X322512MSB4SI; Crystal_SMD_3225-4Pin_3.2x2.5mm

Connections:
3V3_PGOOD: J2.16, R24.2, U7.5, U8.3
+1V8: C10.1, C11.1, C14.1, C19.1, C29.1, C37.1, Q4.1, R14.1, R29.1, R30.1, R50.2, R52.2, R54.2, R79.1, R89.1, U5.2, U6.2, U8.5, U9.2, U15.3, U18.8
+3V3: C4.1, C12.1, C13.1, C16.1, C18.1, C20.1, C21.1, C30.1, C36.1, C60.1, C62.1, FB1.2, J2.2, J2.19, J2.20, J6.1, J6.17, L1.2, R10.2, R13.1, R15.1, R17.1, R21.1, R24.1, R25.1, R26.1, R27.1, R28.1, R40.1, R45.1, U5.19, U6.19, U8.1, U9.19, U22.4, U22.6, U23.15, U23.23, U23.27
+3V3_HDMI: C28.1, C56.1, Q10.1, Q11.1, Q13.1, Q14.1, R58.1, R71.1, R72.1, R80.2, R81.1, R90.1, U22.1
+5V: C15.1, C17.1, C22.1, C23.1, C24.1, C39.1, C71.1, D6.2, D7.2, J3.4, J4.2, J5.251, J5.252, J5.253, J5.254, J5.255, J5.256, J5.257, J5.258, J5.259, J5.260, J6.2, J6.4, J10.2, R1.1, R2.1, R4.1, R5.2, R6.1, R7.1, R16.1, R19.1, R20.1, R33.1, R34.1, R35.1, R38.1, TH1.2, TH2.2, TH3.2, TH4.2, U1.5, U2.5, U3.5, U4.1, U4.5, U7.4, U10.5, U24.5
+5V_HDMI: C72.1, J11.18, R77.2, R78.2, U10.1
/3.3V and 1.8V Power Supply/3V3BUCK_CAP_IN: C25.1, R21.2, R22.1
/3.3V and 1.8V Power Supply/3V3BUCK_FB: C25.2, R22.2, R23.1, U7.6
/3.3V and 1.8V Power Supply/3V3BUCK_SW: L1.1, U7.3
/HDMI Connections Part 1/HDMI_DDC_SCL_POL_CON: J11.15, Q11.3, R77.1
/HDMI Connections Part 1/HDMI_DDC_SDA_POL_CON: J11.16, Q13.3, R78.1
/HDMI Connections Part 1/HDMI_ON: Q10.3, R59.2, R60.2, R61.2, R62.2, R63.2, R64.2, R65.2, R66.2
/HDMI Connections Part 1/HDMI_TX0_CON_N: D19.4, D19.7, FL5.3, J11.9, R70.2
/HDMI Connections Part 1/HDMI_TX0_CON_P: D19.5, D19.6, FL5.4, J11.7, R69.2
/HDMI Connections Part 1/HDMI_TX0_FILT_N: C54.1, FL5.2, R61.1, R70.1
/HDMI Connections Part 1/HDMI_TX0_FILT_P: C50.1, FL5.1, R62.1, R69.1
/HDMI Connections Part 1/HDMI_TX1_CON_N: D18.1, D18.10, FL6.3, J11.6, R74.2
/HDMI Connections Part 1/HDMI_TX1_CON_P: D18.2, D18.9, FL6.4, J11.4, R73.2
/HDMI Connections Part 1/HDMI_TX1_FILT_N: C53.1, FL6.2, R63.1, R74.1
/HDMI Connections Part 1/HDMI_TX1_FILT_P: C49.1, FL6.1, R64.1, R73.1
/HDMI Connections Part 1/HDMI_TX2_CON_N: D18.4, D18.7, FL4.3, J11.3, R68.2
/HDMI Connections Part 1/HDMI_TX2_CON_P: D18.5, D18.6, FL4.4, J11.1, R67.2
/HDMI Connections Part 1/HDMI_TX2_FILT_N: C52.1, FL4.2, R65.1, R68.1
/HDMI Connections Part 1/HDMI_TX2_FILT_P: C48.1, FL4.1, R66.1, R67.1
/HDMI Connections Part 1/HDMI_TXC_CON_N: D19.1, D19.10, FL7.3, J11.12, R76.2
/HDMI Connections Part 1/HDMI_TXC_CON_P: D19.2, D19.9, FL7.4, J11.10, R75.2
/HDMI Connections Part 1/HDMI_TXC_FILT_N: C55.1, FL7.2, R59.1, R76.1
/HDMI Connections Part 1/HDMI_TXC_FILT_P: C51.1, FL7.1, R60.1, R75.1
/HDMI Connections Part 2/HDMI_PWR_EN: R90.2, U10.4
/HDMI Connections Part 2/HDMI_PWR_ILIM: R91.1, U10.3
/Level Shifters and GPIO Header/OE_UART_LVLSHIFT: R40.2, U15.6
/Level Shifters and GPIO Header/VCCB_UART_LVLSHIFT: C38.1, R44.2, R45.2, U15.7
/OLED Display/DATA_CMD: J2.15, R9.1, R10.1
/OLED Display/IREF: J2.4, R11.1
/OLED Display/OLED_COM_HI: C8.1, J2.3
/Power ON/OFF Logic/LATCH_RESET: Q2.3, R5.1, TP1.1, U1.1, U2.4, U3.2
/Power ON/OFF Logic/LATCH_SET: C2.1, J1.1, R4.2, TP2.1, U24.1
/Power ON/OFF Logic/POWER_EN_Q: D1.1, R6.2, R8.1, U3.1, U24.4
/Power ON/OFF Logic/POWER_EN_Q_NOT: R7.2, U3.4, U24.2
/Power ON/OFF Logic/POWER_EN_Q_R: C3.1, D1.2, R8.2, U4.2
/Power ON/OFF Logic/SHUTDOWN_Q2_G: C1.1, C31.1, C32.1, C33.1, Q2.1, R39.1
/Power ON/OFF Logic/SHUTDOWN_WAIT: Q1.3, R2.2, R39.2
/Power Regulation and Fan Tach/FAN_PWM_INV: Q3.1, Q12.3, R16.2
/Power Regulation and Fan Tach/FAN_PWM_LS: J4.4, Q3.3, R19.2
/Power Regulation and Fan Tach/FAN_TACH_IN: J4.3, Q4.3, R20.2
/SODIMM Connections Part 2/VIS_LED_OUT: D7.1, R37.1
/SODIMM Connections Part 2/VIS_SW_D: Q6.3, R37.2
/SODIMM Connections Part 2/VIS_SW_G: Q6.1, R36.2
/SODIMM Connections Part 3/FORCE_RECOVERY*: C46.1, J5.214, R35.2, S3.1, S3.2
/Servo Header and EEPROM/EEPROM_A0: R54.1, R55.2, U18.1
/Servo Header and EEPROM/EEPROM_A1: R52.1, R53.2, U18.2
/Servo Header and EEPROM/EEPROM_A2: R50.1, R51.2, U18.3
/Servo Header and EEPROM/WRITE_PROTEC: R56.2, R57.2, U18.7
/UART to USB Bridge/UART_XTAL_IN: C73.1, U16.7, Y2.1
/UART to USB Bridge/UART_XTAL_OUT: C74.1, U16.8, Y2.3
/UART to USB Bridge/USB2_DN: D9.1, D9.6, FL2.1, J8.2, R47.1
/UART to USB Bridge/USB2_DP: D9.3, D9.4, FL2.2, J8.3, R46.1
/UART to USB Bridge/USB2_FILT_N: FL2.4, R47.2, U16.6
/UART to USB Bridge/USB2_FILT_P: FL2.3, R46.2, U16.5
/UART to USB Bridge/VBUS_USB2: C44.1, D9.5, J8.1, U16.16
/USB2.0 Type A Hub/3V3_BEAD: C63.1, FB1.1, U23.5, U23.10, U23.29, U23.36
/USB2.0 Type A Hub/CFG_SEL0: R85.1, U23.24
/USB2.0 Type A Hub/CFG_SEL1: R86.1, U23.25
/USB2.0 Type A Hub/NON_REM0: R87.1, U23.28
/USB2.0 Type A Hub/NON_REM1: R88.1, U23.22
/USB2.0 Type A Hub/USB1_AP_N: FL3.4, R48.2, U23.30
/USB2.0 Type A Hub/USB1_AP_P: FL3.3, R49.2, U23.31
/USB2.0 Type A Hub/USB1_CR_FILT: C47.1, C61.1, U23.14
/USB2.0 Type A Hub/USB1_PLL_FILT: C45.1, C70.1, U23.34
/USB2.0 Type A Hub/USB1_XTAL_IN: C64.1, U23.33, Y1.1
/USB2.0 Type A Hub/USB1_XTAL_OUT: C65.1, U23.32, Y1.3
/USB2.0 Type A Hub/USB_DSP1_DN: D11.1, D11.6, J9.2, U23.8
/USB2.0 Type A Hub/USB_DSP1_DP: D11.3, D11.4, J9.3, U23.9
/USB2.0 Type A Hub/USB_DSP1_VBUS: C68.1, D11.5, J9.1, TH3.1
/USB2.0 Type A Hub/USB_DSP2_DN: D5.1, D5.6, J12.2, U23.1
/USB2.0 Type A Hub/USB_DSP2_DP: D5.3, D5.4, J12.3, U23.2
/USB2.0 Type A Hub/USB_DSP2_VBUS: C69.1, D5.5, J12.1, TH1.1
/USB2.0 Type A Hub/USB_DSP3_DN: D20.3, D20.4, J9.6, U23.6
/USB2.0 Type A Hub/USB_DSP3_DP: D20.1, D20.6, J9.7, U23.7
/USB2.0 Type A Hub/USB_DSP3_VBUS: C66.1, D20.5, J9.5, TH4.1
/USB2.0 Type A Hub/USB_DSP4_DN: D10.1, D10.6, J12.6, U23.3
/USB2.0 Type A Hub/USB_DSP4_DP: D10.3, D10.4, J12.7, U23.4
/USB2.0 Type A Hub/USB_DSP4_VBUS: C67.1, D10.5, J12.5, TH2.1
/uUSB Connections/USB0_FILT_N: D2.3, D2.4, FL1.1, J7.2, R42.1
/uUSB Connections/USB0_FILT_P: D2.1, D2.6, FL1.2, J7.3, R41.1
/uUSB Connections/VBUS_USB0: C40.1, D2.5, J7.1, Q5.1, R43.1
GND: C1.2, C2.2, C3.2, C4.2, C8.2, C10.2, C11.2, C12.2, C13.2, C14.2, C15.2, C16.2, C17.2, C18.2, C19.2, C20.2, C21.2, C22.2, C23.2, C24.2, C26.2, C27.2, C28.2, C29.2, C30.2, C31.2, C32.2, C33.2, C36.2, C37.2, C38.2, C39.2, C40.2, C41.2, C44.2, C45.2, C46.2, C47.2, C56.2, C57.2, C58.2, C59.2, C60.2, C61.2, C62.2, C63.2, C64.2, C65.2, C66.2, C67.2, C68.2, C69.2, C70.2, C71.2, C72.2, C73.2, C74.2, D2.2, D5.2, D8.2, D9.2, D10.2, D11.2, D12.2, D13.2, D14.2, D15.2, D16.2, D17.2, D18.3, D18.8, D19.3, D19.8, D20.2, J2.5, J2.6, J2.7, J2.8, J2.9, J2.13, J2.14, J2.17, J2.18, J2.22, J2.23, J3.2, J3.3, J4.1, J5.1, J5.2, J5.7, J5.8, J5.13, J5.14, J5.19, J5.20, J5.25, J5.26, J5.31, J5.32, J5.37, J5.38, J5.43, J5.44, J5.49, J5.50, J5.55, J5.56, J5.61, J5.62, J5.67, J5.68, J5.73, J5.74, J5.79, J5.80, J5.85, J5.86, J5.102, J5.107, J5.113, J5.119, J5.125, J5.129, J5.132, J5.135, J5.138, J5.141, J5.144, J5.146, J5.147, J5.152, J5.153, J5.158, J5.159, J5.164, J5.165, J5.170, J5.171, J5.176, J5.177, J5.200, J5.201, J5.217, J5.231, J5.241, J5.242, J5.243, J5.244, J5.245, J5.246, J5.247, J5.248, J5.249, J5.250, J6.6, J6.9, J6.14, J6.20, J6.25, J6.30, J6.34, J6.39, J7.5, J7.6, J8.5, J8.6, J9.4, J9.8, J9.9, J10.3, J11.2, J11.5, J11.8, J11.11, J11.17, J11.SH, J12.4, J12.8, J12.9, Q1.2, Q2.2, Q3.2, Q5.2, Q6.2, Q7.2, Q8.2, Q9.2, Q10.2, Q12.2, R3.2, R9.2, R11.2, R12.2, R18.2, R23.2, R43.2, R51.1, R53.1, R55.1, R56.1, R58.2, R82.2, R84.2, R85.2, R86.2, R87.2, R88.2, R91.2, S1.3, S1.4, S2.1, S2.2, S3.3, S3.4, U1.3, U2.3, U3.3, U4.3, U5.11, U6.11, U7.2, U8.2, U9.11, U10.2, U15.2, U16.1, U16.9, U16.15, U18.4, U22.2, U22.5, U23.11, U23.37, U24.3, Y1.2, Y1.4, Y2.2, Y2.4
GPIO00: J5.87, Q5.3
GPIO01: J5.118, U9.7
GPIO01_LS: J6.29, U9.14
GPIO02: J5.124, R57.1
GPIO03: J5.126, R36.1
GPIO04: J5.127, R31.1
GPIO07: J5.206, Q9.1, R18.1, U9.8
GPIO07_LS: J6.32, U9.13
GPIO08: J5.208, Q4.2, R14.2
GPIO09: J5.211, U5.1
GPIO09_LS: J6.7, U5.20
GPIO11: J5.216, U9.9
GPIO11_LS: J6.31, U9.12
GPIO12: J5.218, U5.9
GPIO12_LS: J6.15, U5.12
GPIO13: J5.228, U5.8
GPIO13_LS: J6.33, U5.13
GPIO14: J5.230, Q12.1, R12.1
HDMI_CEC: D4.1, J5.94, Q14.2, R81.2
HDMI_CEC_CON: C57.1, D8.1, J11.13, L2.2
HDMI_DDC_SCL_POL: J5.100, Q11.2, R71.2
HDMI_DDC_SDA_POL: J5.98, Q13.2, R72.2
HDMI_HPD: J5.96, Q8.3, R79.2
HDMI_HPD_CON: C58.1, C59.1, J11.19, R83.1
HDMI_TXC_N: C55.2, J5.81
HDMI_TXC_P: C51.2, J5.83
HDMI_TXD0_N: C54.2, J5.75
HDMI_TXD0_P: C50.2, J5.77
HDMI_TXD1_N: C53.2, J5.69
HDMI_TXD1_P: C49.2, J5.71
HDMI_TXD2_N: C52.2, J5.63
HDMI_TXD2_P: C48.2, J5.65
I2C0_SCL: D14.1, J2.12, J5.185, J6.28, R25.2
I2C0_SDA: D12.1, J2.10, J2.11, J5.187, J6.27, R26.2
I2C1_SCL: D13.1, J5.189, J6.5, R27.2
I2C1_SDA: D17.1, J5.191, J6.3, R28.2
I2C2_SCL: D15.1, J5.232, R29.2, U18.6
I2C2_SDA: D16.1, J5.234, R30.2, U18.5
I2S0_LRCK: J5.197, U6.7
I2S0_LRCK_LS: J6.35, U6.14
I2S0_SCLK: J5.199, U6.6
I2S0_SCLK_LS: J6.12, U6.15
I2S0_SDIN: J5.195, U6.8
I2S0_SDIN_LS: J6.38, U6.13
I2S0_SDOUT: J5.193, U6.9
I2S0_SDOUT_LS: J6.40, U6.12
MOD_SLEEP*: J5.178, R84.1, U22.3
unnamed: D4.2, R80.1
unnamed: D4.3, L2.1, Q14.3
unnamed: D6.1, R32.1
unnamed: J1.2, R1.2, U1.4
unnamed: Q7.1, R31.2, R89.2
unnamed: Q7.3, R32.2
unnamed: Q8.1, R82.1, R83.2
unnamed: R3.1, U23.35
unnamed: R13.2, U5.10
unnamed: R15.2, U6.10
unnamed: R17.2, U9.10
POWER_EN: J5.237, TP3.1, U4.4
REGOUT_3V3: C41.1, R44.1, U16.4
SERVO_PWM: J10.1, Q9.3, R38.2
SHUTDOWN_REQ*: J5.233, U2.2
SLEEP_WAKE*: C27.1, J5.240, Q1.1, R34.2, S2.3, S2.4, U1.2
SPI0_CS0: J5.95, U5.4
SPI0_CS0_LS: J6.24, U5.17
SPI0_CS1: J5.97, U5.3
SPI0_CS1_LS: J6.26, U5.18
SPI0_MISO: J5.93, U5.5
SPI0_MISO_LS: J6.21, U5.16
SPI0_MOSI: J5.89, U5.7
SPI0_MOSI_LS: J6.19, U5.14
SPI0_SCK: J5.91, U5.6
SPI0_SCK_LS: J6.23, U5.15
SPI1_CS0: J5.110, U9.5
SPI1_CS0_LS: J6.18, U9.16
SPI1_CS1: J5.112, U9.6
SPI1_CS1_LS: J6.16, U9.15
SPI1_MISO: J5.108, U9.4
SPI1_MISO_LS: J6.22, U9.17
SPI1_MOSI: J5.104, U9.1
SPI1_MOSI_LS: J6.37, U9.20
SPI1_SCK: J5.106, U9.3
SPI1_SCK_LS: J6.13, U9.18
SYS_RESET*: C26.1, J5.239, R33.2, S1.1, S1.2, U7.1, U23.26
UART1_CTS: J5.209, U6.1
UART1_CTS_LS: J6.36, U6.20
UART1_RTS: J5.207, U6.3
UART1_RTS_LS: J6.11, U6.18
UART1_RXD: J5.205, U6.4
UART1_RXD_LS: J6.10, U6.17
UART1_TXD: J5.203, U6.5
UART1_TXD_LS: J6.8, U6.16
UART2_RXD: J5.238, U15.4
UART2_RXD_3v3: U15.1, U16.2
UART2_TXD: J5.236, U15.5
UART2_TXD_3v3: U15.8, U16.3
USB0_D_N: FL1.4, J5.109, R42.2
USB0_D_P: FL1.3, J5.111, R41.2
USB1_D_N: FL3.1, J5.115, R48.1
USB1_D_P: FL3.2, J5.117, R49.1

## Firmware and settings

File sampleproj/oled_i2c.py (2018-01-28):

# Code adapted from WiseChip's provided I2C code for the QG-2864KLBEG01 display
# Tests OLED by filling the display, and displaying a picture followed by "hello world"

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

from machine import Pin
from smbus2 import SMBus
import time

# define pins - is there a better way to do this? the machine.Pin package doesn't allow for bidirectional pins
RESET = Pin(9, pin.IN)
SCL = Pin(18, pin.IN)
SDA = Pin(19) # bidirectional

global addr
addr = 120 # OLED device address
global bus
bus = SMBus(1)

# instructions are written to address 64, data to address 0
global ins
ins = 64
global data
data = 0

# coding for picture
sample = [255,1,1,1,1,1,1,1,1,1,1,1,113,145,113,145,145,113,113,145,113,145,145,113,113,145,113,145,145,113,1,1,
1,1,1,1,1,65,241,65,1,1,129,65,65,65,129,1,65,193,65,65,129,1,65,193,1,193,65,193,65,65,209,1,1,1,65,193,65,65,
129,1,1,1,1,1,1,1,1,129,65,65,193,1,65,193,65,65,129,1,1,1,1,1,1,1,1,129,65,65,193,1,129,65,65,65,129,1,193,65,
193,65,129,1,1,1,1,1,1,1,1,1,1,1,1,1,1,255,255,0,0,0,0,0,0,0,0,0,0,0,0,7,0,1,7,0,0,7,0,1,7,0,0,7,0,1,7,0,0,4,0,
0,0,0,0,0,3,4,0,0,3,4,4,4,3,0,8,15,12,4,3,0,0,3,6,1,6,3,0,4,7,4,0,0,4,7,4,0,7,4,16,16,16,16,16,0,0,3,4,4,4,0,4,
7,4,0,7,4,0,4,0,0,0,0,0,3,4,4,4,0,3,4,4,4,3,0,7,0,7,0,7,0,0,0,0,0,0,0,0,0,0,0,0,0,0,255,255,0,0,0,0,128,128,128,
128,128,128,128,0,0,0,0,0,0,0,0,0,0,0,0,0,0,0,0,0,0,0,0,0,0,0,0,0,0,0,0,0,0,0,0,0,0,0,0,0,0,0,128,128,0,0,0,0,0,
0,0,0,0,0,0,0,0,0,0,0,0,0,0,0,0,0,0,0,0,0,0,0,0,0,0,128,128,128,0,0,0,0,0,128,128,128,0,0,0,0,0,0,0,0,128,128,128,
128,128,128,128,128,0,0,0,128,128,128,128,128,128,0,0,0,0,0,0,0,255,255,0,0,0,3,0,0,0,255,0,0,0,3,0,0,192,32,16,
16,16,16,32,192,0,0,0,16,160,32,16,16,16,16,32,192,0,16,112,144,0,144,112,144,0,208,112,16,0,0,0,16,17,241,0,0,0,
0,0,0,16,160,32,16,16,16,16,224,0,0,0,0,0,0,0,0,0,0,0,0,0,0,252,2,1,0,0,0,1,2,252,0,0,0,255,0,0,0,0,0,0,0,0,0,0,
255,32,32,32,32,248,1,2,0,0,0,255,0,0,0,0,1,6,248,0,0,0,0,255,255,0,0,0,0,0,0,16,31,16,0,0,0,0,0,7,8,16,16,16,16,
8,7,0,0,0,128,255,136,16,16,16,16,8,7,0,0,0,7,24,7,0,7,24,7,0,0,0,0,0,16,16,31,16,16,0,0,0,0,16,31,16,0,0,0,16,31,
16,0,128,128,128,128,128,128,128,128,128,128,0,0,3,4,8,16,16,16,8,4,3,0,0,16,31,16,16,16,16,16,24,4,0,0,16,31,16,
16,16,16,16,24,4,0,0,16,31,16,16,16,16,8,6,1,0,0,0,0,255,255,0,0,0,0,0,0,0,0,0,0,64,192,64,64,192,0,0,0,0,0,0,0,0,
0,0,0,0,0,0,0,0,0,0,0,0,128,64,64,128,0,0,64,64,192,64,0,0,192,64,64,64,0,0,192,64,64,64,0,0,0,0,0,0,0,0,128,64,64,
128,0,0,128,64,64,128,0,0,128,64,64,128,0,0,0,128,224,0,0,0,128,64,64,128,0,0,0,128,224,0,0,0,128,64,64,128,0,0,128,
64,64,128,0,0,0,0,0,0,0,0,0,0,0,0,0,0,0,255,255,0,0,0,0,0,0,0,0,0,0,16,31,18,7,0,0,10,21,21,30,16,0,17,27,21,27,17,
0,0,0,17,0,0,0,0,15,16,16,15,0,0,0,30,1,0,0,0,9,17,17,14,0,0,9,17,17,14,0,1,1,1,1,1,0,0,13,18,18,13,0,0,8,18,18,13,
0,0,13,18,18,13,0,6,5,4,31,4,0,0,1,18,18,15,0,6,5,4,31,4,0,0,1,18,18,15,0,0,24,20,18,17,0,0,0,0,0,0,0,0,0,0,0,0,0,0,
0,255,255,128,128,128,128,128,128,128,128,128,128,128,128,128,128,128,128,128,128,128,128,128,128,128,128,128,128,
128,128,128,128,128,128,128,128,128,128,128,128,128,128,128,128,128,128,128,128,128,128,128,128,128,128,128,128,128,
128,128,128,128,128,128,128,128,128,128,128,128,128,128,128,128,128,128,128,128,128,128,128,128,128,128,128,128,128,
128,128,128,128,128,128,128,128,128,128,128,128,128,128,128,128,128,128,128,128,128,128,128,128,128,128,128,128,128,
128,128,128,128,128,128,128,128,128,128,128,128,128,255]

# helloworld
# generated using Krita according to these instructions: https://create.arduino.cc/projecthub/138689/pixel-art-on-oled-display-7f8697
helloworld = [255,255,3,0,0,0,0,0,0,0,0,0,0,192,255, 255,255,255,3,0,0,0,0,0,0,0,0,0,0,192,255,255,255,255,3,0,0,0,0,
0,0,0,0,0,0,192,255,255,255,255,3,0,0,0,0,0,0,0,0,0,0,192,255,255,255,255,3,0,0,0,0,0,0,0,0,0,0,192,255,255,255,255,3,
0,0,0,0,0,0,0,0,0,0,192,255,255,255,255,3,0,0,0,0,0,0,0,0,0,0,192,255,255,255,255,3,0,0,0,0,0,0,0,0,0,0,192,255,255,
255,255,3,0,0,0,0,0,0,0,0,0,0,192,255,255,255,255,3,0,0,0,0,0,0,0,0,0,0,192,255,255,255,255,3,0,0,0,0,0,0,0,0,0,0,192,
255,255,255,255,3,0,0,0,0,0,0,0,0,0,0,192,255,255,255,255,3,0,0,0,0,0,0,0,0,0,0,192,255,255,255,255,3,0,0,0,0,0,0,0,0,
0,0,192,255,255,255,255,3,0,0,0,0,0,0,240,3,0,0,192,255,255,255,255,3,7,206,255,57,224,0,252,7,0,0,192,255,255,255,255,
3,7,206,255,57,224,0,254,15,0,0,192,255,255,255,255,3,7,206,255,57,224,0,30,30,0,0,192,255,255,255,255,3,7,206,1,56,224,
0,15,60,0,0,192,255,255,255,255,3,7,206,1,56,224,0,7,56,0,0,192,255,255,255,255,3,255,207,255,56,224,128,7,120,0,0,192,
255,255,255,255,3,255,207,255,56,224,128,3,112,0,0,192,255,255,255,255,3,255,207,255,56,224,128,3,112,0,0,192,255,255,
255,255,3,7,206,1,56,224,128,7,120,0,0,192,255,255,255,255,3,7,206,1,56,224,0,7,56,0,0,192,255,255,255,255,3,7,206,1,56,
224,0,15,60,0,0,192,255,255,255,255,3,7,206,255,57,224,0,30,30,0,0,192,255,255,255,255,3,7,206,255,249,239,127,252,15,0,
0,192,255,255,255,255,3,7,206,255,249,239,127,248,7,0,0,192,255,255,255,255,3,0,0,0,0,0,0,240,3,0,0,192,255,255,255,255,
3,0,0,0,0,0,0,0,0,0,0,192,255,255,255,255,3,0,0,0,0,0,0,0,0,0,0,192,255,255,255,255,3,0,0,0,0,0,0,0,0,0,0,192,255,255,255,
255,3,0,0,0,0,0,0,0,0,0,0,192,255,255,255,255,3,0,0,0,0,0,0,0,0,0,0,192,255,255,255,255,3,0,0,0,0,0,0,0,0,0,0,192,255,255,
255,255,131,3,3,135,31,248,15, 6,248,7,12,192,255,255,255,255,131,7,135,231,127,248, 31,6,248,31,12,192,255,255,255,255,3,
135,135,243,96,24,56,6,56,56,12,192,255,255,255,255,3,199,143,115,224,24,48,6,24,48,12,192,255,255,255,255,3,199,143,59,
192,25,48,6,56,112,12,192,255,255,255,255,3,239,223,59,192,25,48,6,24,96,12,192,255,255,255,255,3,238,220,57,192,249,63,
7,56,96,12,192,255,255,255,255,3,238,220,57,192,249,31,6,24,96,12,192,255,255,255,255,3,238,220,57,192,185,15,6,56,96,12,
192,255,255,255,255,3,236,220,56,192,25,15,6,24,96,12,192,255,255,255,255,3,124,248,48,192,24,30,6,56,112,12,192,255,255,
255,255,3,124,248,112,224,24,60,6,24,48,8,192,255,255,255,255,3,124,248,224,127,56,120,254,59,61,12,192,255,255,255,255,3,
56,112,192,127,24,112,254,251,31,12,192,255,255,255,255,3,16,32,128,31,24,96,254,251,15,8,192,255,255,255,255,3,0,0,0,0,0,
0,0,0,0,0,192,255,255,255,255,3,0,0,0,0,0,0,0,0,0,0,192,255,255,255,255,3,0,0,0,0,0,0,0,0,0,0,192,255,255,255,255,3,0,0,0,
0,0,0,0,0,0,0,192,255,255,255,255,3,0,0,0,0,0,0,0,0,0,0,192,255,255,255,255,3,0,0,0,0,0,0,0,0,0,0,192,255,255,255,255,3,0,
0,0,0,0,0,0,0,0,0,192,255,255,255,255,3,0,0,0,0,0,0,0,0,0,0,192,255,255,255,255,3,0,0,0,0,0,0,0,0,0,0,192,255,255,255,255,
3,0,0,0,0,0,0,0,0,0,0,192,255,255,255,255,3,0,0,0,0,0,0,0,0,0,0,192,255,255,255,255,3,0,0,0,0,0,0,0,0,0,0,192,255,255,255,
255,3,0,0,0,0,0,0,0,0,0,0,192,255,255]

def setup():
    # resets addresses on display, sets up clocks, and turns on display
    seq = [174, 0, 16, 64, 129, 143, 17, 22, 24, 63, 200, 211, 0,
        213, 128, 217, 34, 218, 18, 219, 64, 141, 20, 175]
    bus.write_i2c_block_data(addr, ins, seq)

def fill(col1, col2):
    # fills portion of screen from column 1 to 2
    set_start()
    bus.write_byte_data(addr, ins, 176) # set page

    for y in range (0, 8):
        set_start()
        newpage = 176 + y
        bus.write_byte_data(addr, ins, newpage)

        for x in range(0, 64):
            bus.write_byte_data(addr, data, col1)
            bus.write_byte_data(addr, data, col2)

def pane():
    # fills certain pane of screen
    set_start()
    bus.write_byte_data(addr, ins, 176) # set page

    for x in range(0,126):
        bus.write_byte_data(addr, data, 1)

    bus.write_byte_data(addr, data, 255)

    set_start()
    bus.write_byte_data(addr, ins, 177) # increment page
    bus.write_byte_data(addr, data, 255)

    for x in range(0, 94):
        bus.write_byte_data(addr, data, 128)
    bus.write_byte_data(addr, data, 255)

def set_start():
    # sets lower and higher column addresses to 0 and 16, respectively
    bus.write_byte_data(addr, ins, 0)   # set lower col start addr
    bus.write_byte_data(addr, ins, 16)  # set higher col start addr

def picture(image):
    # displays a provided picture on every page (8 times), coded as a list of addresses
    i = 0
    set_start()

    for y in range(0,8):
        newpage = 176 + y
        bus.write_byte_data(addr, ins, newpage)
        set_start()

        for x in range(0, 128):
            bus.write_byte_data(addr, data, image[i])
            i += 1

def helloworld(image):
    set_start()
    bus.write_byte_data(addr, ins, 176)

    for i in range(0,8192):
        bus.write_byte_data(addr, data, image[i])

        if i % 1024 == 0:
            newpage = 176 + (i / 1024) # new page number
            bus.write_byte_data(addr, ins, newpage)




if __name__ == "__main__":

    setup()

    fill(255, 255)
    time.sleep(10)

    picture(sample)
    time.sleep(10)

    picture(helloworld)
    time.sleep(10)
else:
    exit

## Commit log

2018-01-28 add i2c functional script from val
2021-07-07 add design and manufacturing files
    [Page1.sch, Page10.sch, Page11.sch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]
2021-07-08 add i2c testing script, delete models
2021-07-08 debugging i2c script
2021-07-09 add schematic to docs file
2021-07-09 add files to docs folder'
    [bom_release.xlsx]
2021-07-09 add spi skeleton
2021-07-13 add documentation and sample project scripts
2021-07-19 use open source filetypes
    [bom_release.csv]
2021-07-26 Add CAD for potential OLED support
    [OLED Display Support.stl]
2021-07-28 Update files for A01
    [BOM_A01.xlsx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]
2021-07-28 rename baseboard
    [baseboard.kicad_pcb, os_baseboard.kicad_pcb]
2021-08-11 remove USB footprint
2021-08-11 add final board pictures
2021-08-12 update A01 files
    [Page1.sch, Page10.sch, Page11.sch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]
2021-08-12 rename & move files for cohesion
    [BOM_A01.xlsx, baseboard.kicad_pcb, baseboard.sch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]
2021-08-12 rename A00 files
    [BOM_A00.csv]

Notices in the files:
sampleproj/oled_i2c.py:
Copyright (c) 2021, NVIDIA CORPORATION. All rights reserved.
